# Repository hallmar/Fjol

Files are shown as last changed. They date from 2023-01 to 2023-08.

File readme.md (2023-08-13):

# Fjöl 4-Voice Midi synth
# FIRMWARE AND HARDWARE STILL A WORK IN PROGRESS

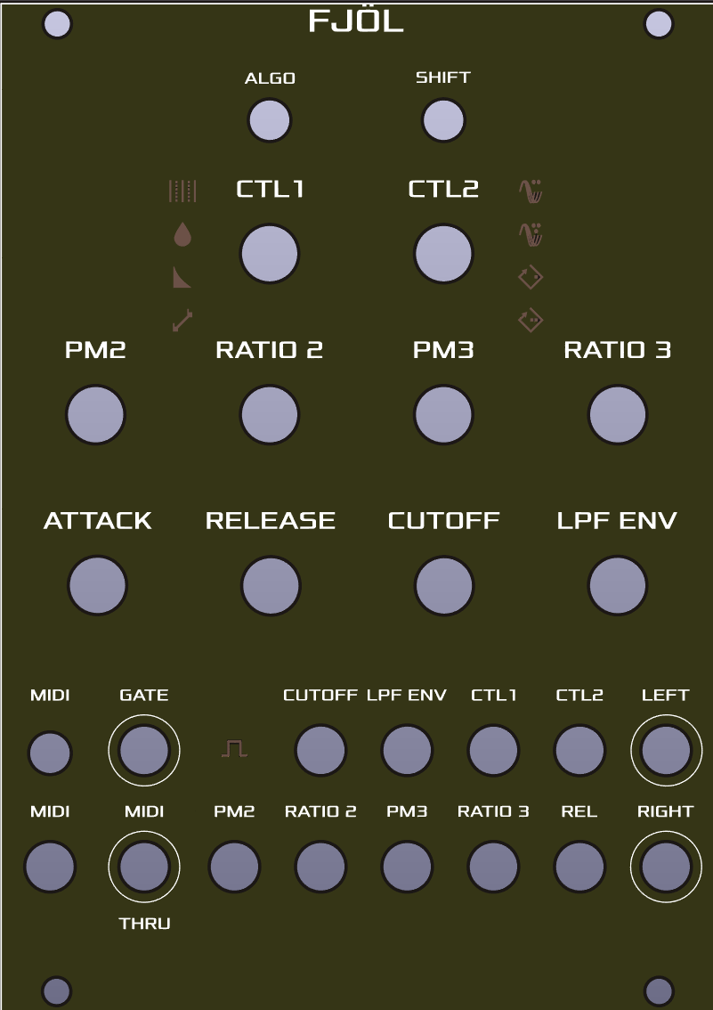
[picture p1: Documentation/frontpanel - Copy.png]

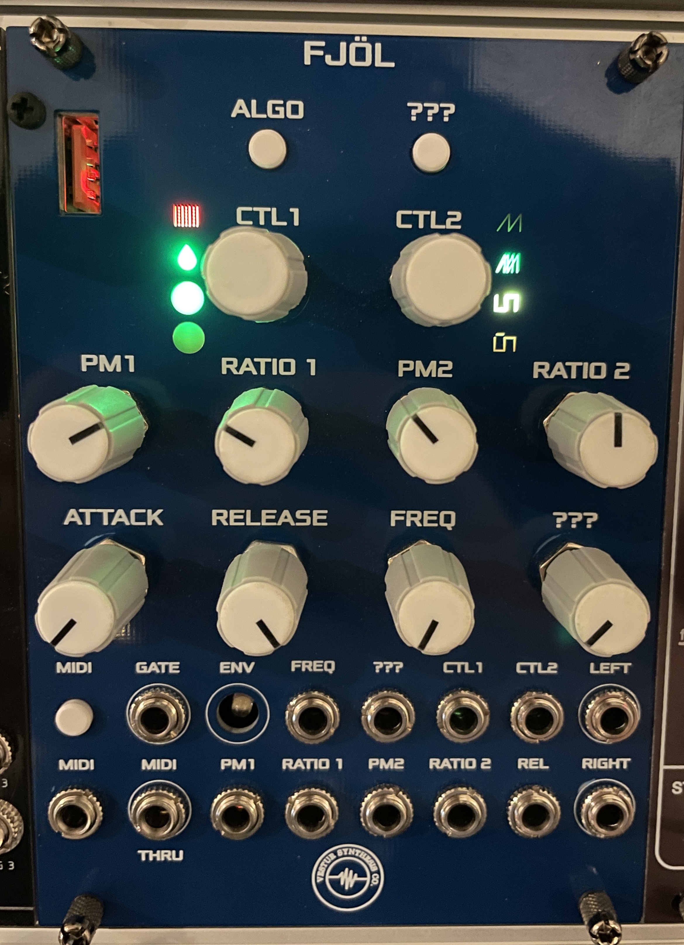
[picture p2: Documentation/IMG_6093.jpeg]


Small demo video with non working LED's: https://www.youtube.com/watch?v=nTqA_WNiwQo

Current hardware uses the [Daisy Seed](https://www.electro-smith.com/daisy) platform from Electrosmith, which has 96kHz/24Bit stereo audio.

Fjöl is a 
4 voice polyphonic Phase modulation synthesizer. Using only sine waves you can get the same sounds as an FM synthesizer.

* digital ladder LPF with resonance
* usb A on the back to update firmware
* 3 operator Phase modulation with 3 algorithms(so far)
* two endless encoders with CV input for adjusting 8 different parameters 
* MIDI IN and MIDI THRU with type A midi minijacks as per MIDI standard.
* optional V/OCT and gate per voice expander also in the works

Encoder parameters are:

* stereo spread of voices(constant power)
* filter resonance
* filter envelope decay
* glide/portamento
* Operator 2 detune
* Operator 3 detune
* Operator 1 feedback (creates saw like wave)
* Operator 2 feedback

Potentiometers are:

* Operator 2 amplitude
* Operator 2 ratio
* Operator 3 amplitude
* Operator 3 ratio
* VCA Attack 
* VCA Release
* LPF frequency
* Filter envelope amplitude

Algorithms so far:

### Algo 1: 

OP2 -> OP1

OP3 -> OP1

### Algo 2:

OP3 -> OP2 -> OP1

### Algo 3:

OP3 -> OP1

OP2 -> OUT

## Where/how to order
It's all a work in progress.

~~Hopefully I'll have some beta testing units ready before summer 2023 :)~~

WELL that didn't work out. Putting this one on hiatus until I finalize the desktop version.
It's a struggle to work a full time job and try and work on this regularily.

## Designed With

* KiCAD
* Visual Studio Code(C++)
* Inkscape

## Versioning
* 1.0 - [Hardware] Original PCB
* 1.0 - [Software] Original software 
## Authors

* **Hallmar Gauti Halldórsson** - Fjöl Hardware and Firmware
* **Electrosmith** - libDaisy and DaisySP libraries

## License
Hardware: CC BY-SA 4.0

Software: CC BY-SA 4.0

But if you want to sell or do something with the software or hardware then it'd be nice to include my name and link to my Github somewhere :)

## Acknowledgments

* All of Mutable Instruments designs have been an insparation and a solid reference for both analog and digital circuits.
https://github.com/pichenettes/eurorack

* The whole idea of a 4 voice poly synth was planted in my head after trying MakeSynthsNotWar's String Theory module.
https://makesynthsnotwar.com/modules/stringtheory/

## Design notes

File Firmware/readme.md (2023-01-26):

# File Structure:
* **Fjol.cpp** is the main file that sets up all the hardware, reads ADC values and ect.
* **led-enc.cpp** this contains the functions to map values for the LED's and a function to return velocity sensitive values from encoders
* **midi.cpp** this contains all the midi functions that handle midi messages
* **variables.cpp** and **variables.h** contain all of the globally declared variables.
* **settings.h** contains all function declerations
* **calibrate.cpp** contains the function for calibrating CV and potentiometer values
* **makefile** contains the build info for this project

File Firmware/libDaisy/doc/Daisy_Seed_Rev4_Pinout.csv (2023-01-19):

 | SCH name | Pin name | ADC | Arduino D# | Arduino A# | I2C | UART | SPI
1 | USB_HS_ID | PB12 | x | D0 |  |  | UART5_RX | SPI2_NSS/I2S2_WS | TIM1_BKIN |  |  | DFSDM1_DATIN1 | USART3_CK | FDCAN2_RX | OTG_HS_ULPI_D5 | ETH_MII_TXD0/ETH_RMII_TXD0 | OTG_HS_ID | TIM1_BKIN_COMP12 |  | EVENTOUT
2 | SDMMC1_D3 | PC11 | x | D1 |  |  | USART3_RX/UART4_RX | SPI3_MISO/ I2S3_SDI | HRTIM_FLT2 | DFSDM1_DATIN5 |  |  |  | QUADSPI_BK2_NCS | SDMMC1_D3 | DCMI_D4 | EVENTOUT
3 | SDMMC1_D2 | PC10 | x | D2 |  |  | USART3_TX/UART4_TX | SPI3_SCK/I2S3_CK | HRTIM_EEV1 | DFSDM1_CKIN5 |  |  |  | QUADSPI_BK1_IO1 | SDMMC1_D2 | DCMI_D8 | LCD_R2 | EVENTOUT
4 | SDMMC1_D1 | PC9 | x | D3 |  | I2C3_SDA |  |  | MCO2 | TIM3_CH4 | TIM8_CH4 |  | I2S_CKIN | UART5_CTS | QUADSPI_BK1_IO0 | LCD_G3 | SWPMI_SUSPEND | SDMMC1_D1 | DCMI_D3 | LCD_B2 | EVENTOUT
5 | SDMMC1_D0 | PC8 | x | D4 |  |  |  |  | TRACED1 | HRTIM_CHB1 | TIM3_CH3 | TIM8_CH3 | USART6_CK | UART5_RTS/UART5_DE | FMC_NE2/FMC_NCE | SWPMI_RX | SDMMC1_D0 | DCMI_D2 | EVENTOUT
6 | SDMMC1_CMD | PD2 | x | D5 |  |  | UART5_RX |  | TRACED2 | TIM3_ETR |  | SDMMC1_CMD | DCMI_D11 | EVENTOUT
7 | SDMMC1_CK | PC12 | x | D6 |  |  | UART5_TX | SPI3_MOSI/I2S3_SDO | TRACED3 | HRTIM_EEV2 |  |  |  | SDMMC1_CK | DCMI_D9 | EVENTOUT
8 | SPI1_NSS | PG10 | x | D7 |  |  |  | SPI1_NSS/I2S1_WS | HRTIM_FLT5 |  | LCD_G3 |  | FMC_NE3 | DCMI_D2 | LCD_B2 | EVENTOUT
9 | SPI1_SCK | PG11 | x | D8 |  |  |  | SPI1_SCK/I2S1_CK | LPTIM1_IN2 | HRTIM_EEV4 |  | SPDIFRX1_IN1 | SDMMC2_D2 | ETH_MII_TX_EN/ETH_RMII_TX_ EN | DCMI_D3 | LCD_B3 | EVENTOUT
10 | SPI1_MISO | PB4 | x | D9 |  |  | UART7_TX | SPI1_MISO/I2S1_SDI/SPI3_MISO/I2S3_SDI/SPI2_NSS/I2S2_WS/SPI6_MISO | NJTRST | TIM16_BKIN | TIM3_CH1 | HRTIM_EEV6 |  |  |  |  | SDMMC2_D3 |  | EVENTOUT
11 | SPI1_MOSI | PB5 | x | D10 |  |  | UART5_RX | SPI1_MOSI/I2S1_SDO/SPI3_MOSI/I2S3_SDO/SPI6_MOSI | TIM17_BKIN | TIM3_CH2 | HRTIM_EEV7 |  |  |  |  |  | FDCAN2_RX | OTG_HS_ULPI_D7 | ETH_PPS_OUT | FMC_SDCKE1 | DCMI_D10 |  | EVENTOUT
12 | I2C1_SCL | PB8 | x | D11 |  | I2C1_SCL/I2C4_SCL | UART4_RX |  | TIM16_CH1 | TIM4_CH3 | DFSDM1_CKIN7 |  |  | SDMMC1_CKIN |  | FDCAN1_RX | SDMMC2_D4 | ETH_MII_TXD3 | SDMMC1_D4 | DCMI_D6 | LCD_B6 | EVENTOUT
13 | I2C1_SDA | PB9 | x | D12 |  | I2C1_SDA/I2C4_SDA | UART4_TX | SPI2_NSS/I2S2_WS | TIM17_CH1 | TIM4_CH4 | DFSDM1_DATIN7 |  |  |  | SDMMC1_CDIR |  | FDCAN1_TX | SDMMC2_D5 |  | SDMMC1_D5 | DCMI_D7 | LCD_B7 | EVENTOUT
14 | USART1_TX | PB6 | x | D13 |  | I2C1_SCL/I2C4_SCL | USART1_TX/LPUART1_TX/UART5_TX |  | TIM16_CH1N | TIM4_CH1 | HRTIM_EEV8 |  | CEC |  |  |  | FDCAN2_TX | QUADSPI_BK1_NCS | DFSDM1_DATIN5 | FMC_SDNE1 | DCMI_D5 |  | EVENTOUT
15 | USART1_RX | PB7 | x | D14 |  | I2C1_SDA/I2C4_SDA | USART1_RX/LPUART1_RX |  | TIM17_CH1N | TIM4_CH2 | HRTIM_EEV9 |  |  |  |  | FDCAN2_TXFD_MODE | DFSDM1_CKIN5 | FMC_NL | DCMI_VSYNC | EVENTOUT
16 | AUDIO IN L | x | x | NC |  |  |  |  | x
17 | AUDIO INR | x | x | NC |  |  |  |  | x
18 | AUDIO OUT L | x | x | NC |  |  |  |  | x
19 | AUDIO OUT R | x | x | NC |  |  |  |  | x
20 | AGND | x | x | NC
21 | 3v3A | x | x | NC |  |  |  |  | x
22 | ADC_INP10 | PC0 | ADC12_INP10 | D15 | A0 |  |  |  | DFSDM1_CKIN0 | DFSDM1_DATIN4 |  | OTG_HS_ULPI_STP | FMC_SDNWE | LCD_R5 | EVENTOUT
23 | ADC_INP15 | PA3 | ADC12_INP15 | D16 | A1 |  | USART2_RX |  | TIM2_CH4 | TIM5_CH4 | LPTIM5_OUT | TIM15_CH2 |  | LCD_B2 | OTG_HS_ULPI_D0 | ETH_MII_COL | LCD_B5 | EVENTOUT
24 | ADC_INP5 | PB1 | ADC12_INP5 | D17 | A2 |  |  |  | TIM1_CH3N | TIM3_CH4 | TIM8_CH3N | DFSDM1_DATIN1 | LCD_R6 | OTG_HS_ULPI_D2 | ETH_MII_RXD3 | LCD_G0 | EVENTOUT
25 | ADC_INP7 | PA7 | ADC12_INP7 | D18 | A3 |  |  | SPI1_MOSI/I2S1_SDO/SPI6_MOSI | TIM1_CH1N | TIM3_CH2 | TIM8_CH1N |  |  | TIM14_CH1 | ETH_MII_RX_DV/ETH_RMII_CRS _DV | FMC_SDNWE | EVENTOUT
26 | ADC_INP3 | PA6 | ADC12_INP3 | D19 | A4 |  |  | SPI1_MISO/I2S1_SDI/SPI6_MISO | TIM1_BKIN | TIM3_CH1 | TIM8_BKIN |  |  | TIM13_CH1 | TIM8_BKIN_COMP12 | MDIOS_MDC | TIM1_BKIN_COMP12 | DCMI_PIXCLK | LCD_G2 | EVENTOUT
27 | ADC_INP11 | PC1 | ADC123_INP11 | D20 | A5 |  |  | SPI2_MOSI/I2S2_SDO | TRACED0 | SAI1_D1 | DFSDM1_DATIN0 | DFSDM1_CKIN4 |  | SAI1_SD_A | SAI4_SD_A | SDMMC2_CK | SAI4_D1 | ETH_MDC | MDIOS_MDC | EVENTOUT
28 | ADC1_INP4 | PC4 | ADC12_INP4 | D21 | A6 |  |  |  | DFSDM1_CKIN2 | I2S1_MCK | SPDIFRX1_IN3 | ETH_MII_RXD0/ETH_RMII_RXD0 | FMC_SDNE0 | EVENTOUT
29 | DAC1_OUT2 | PA5 | ADC12_INP19 | D22 | A7 |  |  | SPI1_SCK/I2S1_CK/SPI6_SCK | D2PWREN | TIM2_CH1/TIM2_ETR | TIM8_CH1N |  |  | OTG_HS_ULPI_CK | LCD_R4 | EVENTOUT
30 | DAC1_OUT1 | PA4 | ADC12_INP18 | D23 | A8 |  |  | SPI1_NSS/I2S1_WS/SPI3_NSS/I2S3_WS/SPI6_NSS | D1PWREN | TIM5_ETR |  |  | USART2_CK |  | OTG_HS_SOF | DCMI_HSYNC | LCD_VSYNC | EVENTOUT
31 | SAI2_MCLK_B | PA1 | ADC1_INP17 | D24 | A9 |  | UART4_RX |  | TIM2_CH2 | TIM5_CH2 | LPTIM3_OUT | TIM15_CH1N | USART2_RTS/USART2_DE |  | QUADSPI_BK1_IO3 |  | ETH_MII_RX_CLK/ETH_RMII_RE F_CLK | LCD_R2 | EVENTOUT
32 | SAI2_SD_B | PA0 | ADC1_INP16 | D25 | A10 |  | UART4_TX |  | TIM2_CH1/TIM2_ETR | TIM5_CH1 | TIM8_ETR | TIM15_BKIN | USART2_CTS/USART2_NSS |  | SDMMC2_CMD |  | ETH_MII_CRS | EVENTOUT
33 | SAI2_SD_A | PD11 | x | D26 |  |  |  |  | LPTIM2_IN2 |  | USART3_CTS/USART3_NSS | QUADSPI_BK1_IO0 |  | FMC_A16 | EVENTOUT
34 | SAI2_FS_B | PG9 | x | D27 |  |  | USART6_RX | SPI1_MISO/I2S1_SDI |  |  | SPDIFRX1_IN4 | QUADSPI_BK2_IO2 |  | FMC_NE2/FMC_NCE | DCMI_VSYNC | EVENTOUT
35 | SAI2_SCK_B | PA2 | ADC12_INP14 | D28 | A11 |  | USART2_TX |  | TIM2_CH3 | TIM5_CH3 | LPTIM4_OUT | TIM15_CH1 |  |  | ETH_MDIO | MDIOS_MDIO | LCD_R1 | EVENTOUT
36 | USB_HS_D_- | PB14 | x | D29 |  |  | USART1_TX | SPI2_MISO/I2S2_SDI | TIM1_CH2N | TIM12_CH1 | TIM8_CH2N |  |  | DFSDM1_DATIN2 | USART3_RTS/USART3_DE | UART4_RTS/UART4_DE | SDMMC2_D0 | OTG_HS_DM | EVENTOUT
37 | USB_HS_D_+ | PB15 | x | D30 |  |  | USART1_RX | SPI2_MOSI/I2S2_SDO | RTC_REFIN | TIM1_CH3N | TIM12_CH2 | TIM8_CH3N |  |  | DFSDM1_CKIN2 | UART4_CTS | SDMMC2_D1 | OTG_HS_DP | EVENTOUT
38 | 3v3D | x | x |  |  |  |  |  | x
39 | VIN | x | x |  |  |  |  |  | x
40 | GND | x | x |  |  |  |  |  | x
INTERNAL
MEM1 | QSPI | QSPI FLASH 8MB
MEM2 | SDRAM | SDRAM 64MB
 | USB FS D+ | USB FS
 | USB FS D- | USB FS
 |  |  |  |  |  |  |  |  |  |  |  |  |  | LPUART1_TX
internal SAI | I2C2 |  |  |  |  |  |  |  |  |  |  |  |  | LPUART1_RX
 | SAI1_MCLK_A | PE2 |  |  |  |  |  |  |  |  |  |  |  | UART4_RX
 | SAI1_SD_B | PE3 |  |  |  |  |  |  |  |  |  |  |  | UART4_TX
 | SAI1_FS_A | PE4 |  |  |  |  |  |  |  |  |  |  |  | UART5_RX
 | SAI1_SCK_A | PE5 |  |  |  |  |  |  |  |  |  |  |  | UART5_TX
 | SAI1_SD_A | PE6 |  |  |  |  |  |  |  |  |  |  |  | UART7_RX
 |  |  |  |  |  |  |  |  |  |  |  |  |  | UART7_TX
 |  |  |  |  |  |  |  |  |  |  |  |  |  | USART1_RX
On Board User LED | PC7 |  |  | D31 |  |  |  |  |  |  |  |  |  | USART1_TX
On Board Test Point | PG14 |  |  |  |  |  |  |  |  |  |  |  |  | USART2_RX
 |  |  |  |  |  |  |  |  |  |  |  |  |  | USART2_TX
BOOT | PG3 |  |  |  |  |  |  |  |  |  |  |  |  | USART3_RX
QSPI GPIO |  |  |  |  |  |  |  |  |  |  |  |  |  | USART3_TX
IO0 | PF8 |  |  |  |  |  |  |  |  |  |  |  |  | USART6_RX
IO1 | PF9
IO2 | PF7
IO3 | PF6
CLK | PF10
NCS | PG6

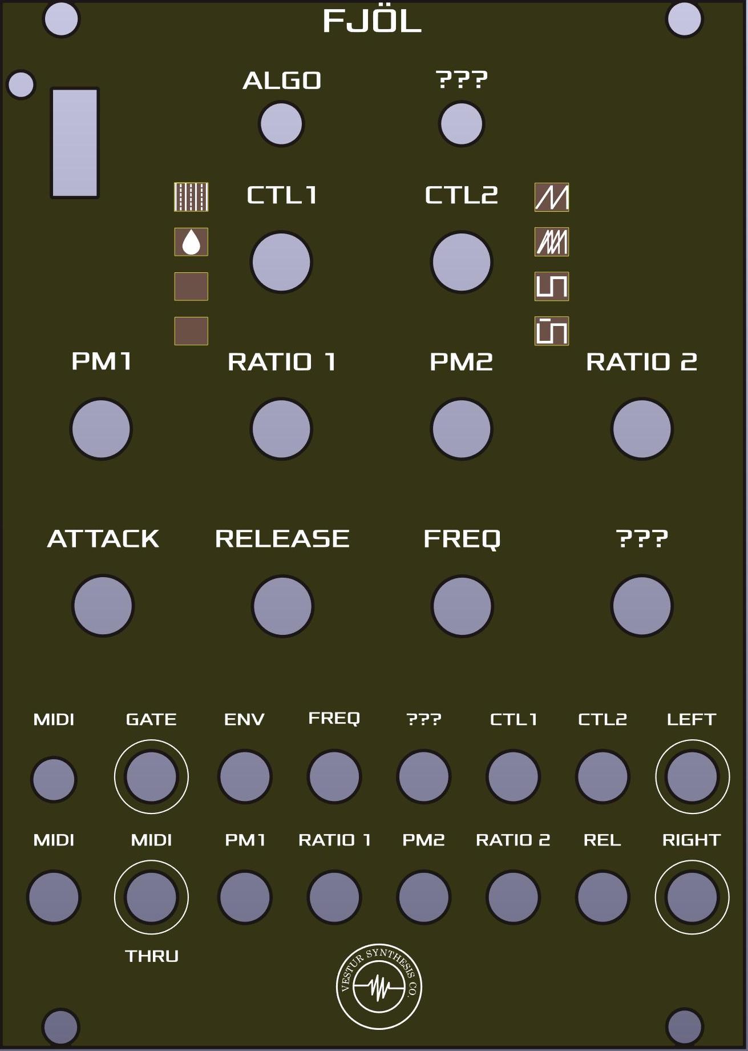
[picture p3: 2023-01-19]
Hardware/frontpanel/frontpanel(1).jpg

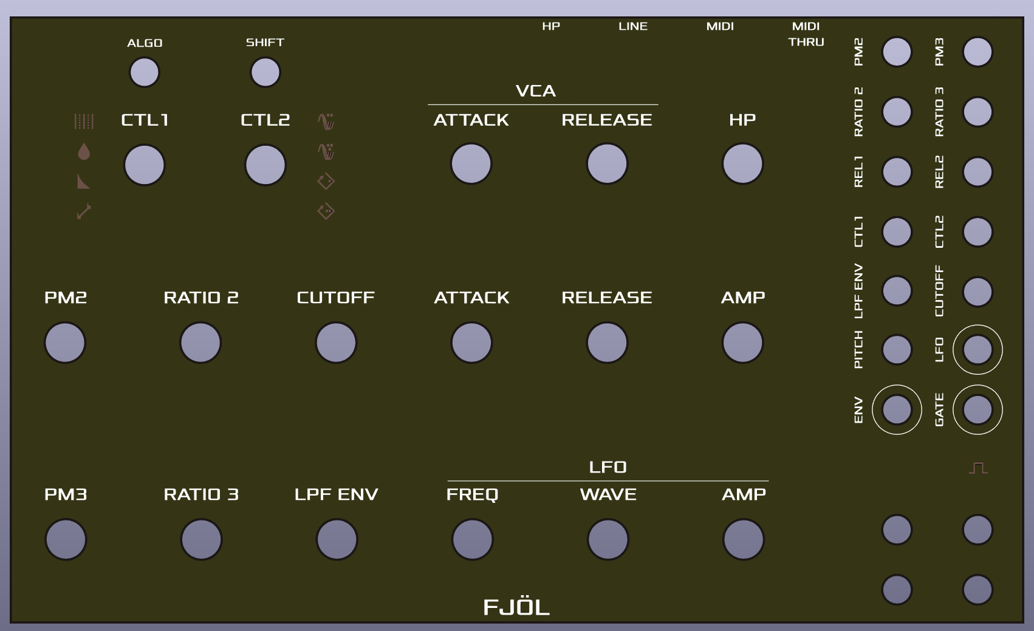
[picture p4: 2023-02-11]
Hardware/frontpanel/Screenshot 2023-02-08 221054.png

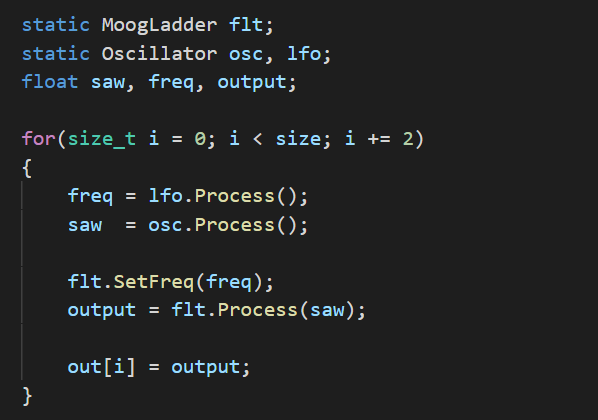
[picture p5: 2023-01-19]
Firmware/DaisySP/resources/assets/code_example.PNG

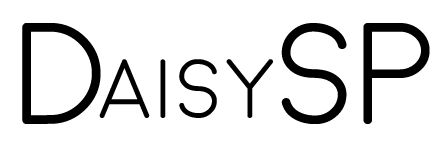
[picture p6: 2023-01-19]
Firmware/DaisySP/resources/assets/daisysp.png

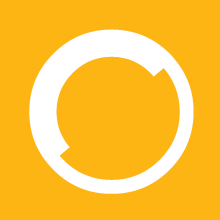
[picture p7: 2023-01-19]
Firmware/libDaisy/doc/images/ES_Circle_Orange.PNG

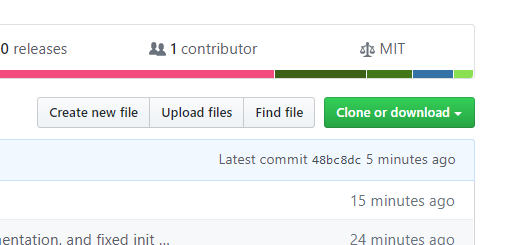
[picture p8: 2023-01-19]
Firmware/DaisySP/resources/download.PNG

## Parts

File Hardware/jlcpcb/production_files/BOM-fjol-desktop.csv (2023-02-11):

Comment | Designator | Footprint | LCSC
22u | C10,C2,C6,C7 | C_Elec_5x5.8 | C128468
LM4040DBZ-10 | U4 | SOT-23 | C129969
470n | C14,C18 | C_0805_2012Metric | C13967
100k | R10,R12,R14,R16,R18,R24,R27,R29,R45,R46,R56,R67,R69 | R_0805_2012Metric | C149504
741G17DBV | IC1 | SOT-23-5_HandSoldering | C151394
100 | R30,R35,R36,R37,R47,R48,R52,R53,R64,R65,R72,R73,R74,R75,R76,R77,R78,R79 | R_0805_2012Metric | C17408
10k | R40,R42,R43,R82,R83,R84,R85,R86,R87,R88,R89 | R_0805_2012Metric | C17414
10 | R51 | R_0805_2012Metric | C17415
140k 1% | R55 | R_0805_2012Metric | C17460
1k | R2,R3,R38,R41,R5,R6,R7 | R_0805_2012Metric | C17513
200k | R11,R13,R15,R17,R23,R25,R26,R28,R39,R44,R66,R68 | R_0805_2012Metric | C17539
220 | R1 | R_0805_2012Metric | C17557
22k | R8,R9 | R_0805_2012Metric | C17560
33k | R49,R54,R57 | R_0805_2012Metric | C17633
33 | R50 | R_0805_2012Metric | C17634
470 | R4 | R_0805_2012Metric | C17710
66.5k | R19,R20,R21,R22,R31,R32,R33,R34,R70,R71 | R_0805_2012Metric | C17791
100p | C30,C31 | C_0805_2012Metric | C1790
2.2u | L12,L2,L3 | L_0805_2012Metric | C193676
1N4148 | D3 | D_SOD-323 | C2128
BC847 | Q1 | SOT-23 | C2138
6N138 | U3 | DIL8-SMD | C255744
NCP1117-3.3_SOT223 | U11 | SOT-223-3_TabPin2 | C26537
LM4810 | U5 | TSSOP-8_3x3mm_P0.65mm | C2871753
AudioJack3 | headphone1,line1 | Jack_3.5mm_CUI_SJ-3523-SMT_Horizontal | C2910522
220u | C21,C22 | CP_Elec_5x5.8 | C2977551
100u | C44,C5 | C_Elec_5x5.8 | C336761
USB_B | J1 | USB_Micro-B_GCT_USB3076-30-A | C393940
33u | L6 | L_0805_2012Metric | C404761
MCP6001-OT | U13 | SOT-23-5 | C412821
1n | C23,C32,C33,C34,C35,C38,C40,C41,C42,C8,C9 | C_0805_2012Metric | C46653
100n | C1,C11,C12,C13,C15,C16,C17,C19,C20,C24,C3,C37,C39,C4,C43,C45,C46,C51,C52 | C_0805_2012Metric | C49678
TL072 | U6 | SO-8_3.9x4.9mm_P1.27mm | C6961
MCP6004 | U10,U7,U9 | SOIC-14_3.9x8.7mm_P1.27mm | C7378
BLM21AG102SN1D | L10,L11,L8,L9 | L_0805_2012Metric | C85835
74HC4051D | U8 | SOIC-16_4.55x10.3mm_P1.27mm | C9386
PESE1-S5-D12-M-TR | U2 | PESE1
PCA9622 | U12 | TSSOP-32_6.1x11mm_P0.65mm
SW_SPST | SW1 | SW_E-Switch_EG1224_SPDT_Angled

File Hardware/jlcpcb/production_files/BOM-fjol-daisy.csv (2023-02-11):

Comment | Designator | Footprint | LCSC
22u | C10,C6,C7 | C_Elec_5x5.8 | C128468
LM4040DBZ-10 | U4 | SOT-23 | C129969
100k 1% | R10,R12,R14,R16,R18,R24,R27,R29,R44,R45,R46,R61,R63,R67,R69 | R_0805_2012Metric | C149504
Conn_02x05_Odd_Even | J2 | PinHeader_2x05_P1.27mm_Vertical_SMD | C150517
741G17DBV | IC1 | SOT-23-5_HandSoldering | C151394
STPS1L30U | D1,D2 | D_SMB | C157388
100 | R30,R35,R36,R37,R52,R53,R64,R65,R72,R73,R74,R75,R76,R77,R78,R79 | R_0805_2012Metric | C17408
10k | R40,R42,R43,R48,R49,R58,R59,R82,R83,R84,R85,R86,R87,R88,R89 | R_0805_2012Metric | C17414
10 | R51 | R_0805_2012Metric | C17415
140k 1% | R47,R60,R62,R9 | R_0805_2012Metric | C17460
1k | R2,R3,R38,R41,R5,R54,R55 | R_0805_2012Metric | C17513
200k | R11,R13,R15,R17,R23,R25,R26,R28,R66,R68 | R_0805_2012Metric | C17539
220 | R1 | R_0805_2012Metric | C17557
33k 1% | R56,R57,R80,R81 | R_0805_2012Metric | C17633
33 | R50 | R_0805_2012Metric | C17634
470 | R4 | R_0805_2012Metric | C17710
47k | R7,R8 | R_0805_2012Metric | C17713
66.5k | R19,R20,R21,R22,R31,R32,R33,R34,R70,R71 | R_0805_2012Metric | C17791
100p | C30,C31 | C_0805_2012Metric | C1790
Conn_01x16_Male | J7 | PinHeader_2x08_P2.54mm_Vertical_SMD | C188235
BC847 | Q1,Q2,Q3,Q4,Q5 | SOT-23 | C2138
6N138 | U3 | DIL8-SMD | C255744
Conn_01x10_Female | J10,J6 | PinSocket_2x05_P2.54mm_Vertical_SMD | C261072
NCP1117-3.3_SOT223 | U11,U2 | SOT-223-3_TabPin2 | C26537
PCA9622 | U12 | TSSOP-32_6.1x11mm_P0.65mm | C2678561
100u | C2,C44,C5 | C_Elec_5x5.8 | C336761
Conn_01x16_Female | J8 | PinSocket_2x08_P2.54mm_Vertical_SMD | C3975153
33u | L12,L2,L6 | L_0805_2012Metric | C404761
1n | C20,C21,C22,C23,C32,C33,C34,C35,C38,C40,C41,C42,C8,C9 | C_0805_2012Metric | C46653
100n | C1,C11,C13,C15,C16,C17,C19,C24,C3,C36,C37,C39,C4,C43,C45,C46,C51,C52 | C_0805_2012Metric | C49678
TL072 | U6 | SO-8_3.9x4.9mm_P1.27mm | C6961
MCP6002 | U13 | SOIC-8-1EP_3.9x4.9mm_P1.27mm_EP2.514x3.2mm | C7377
MCP6004 | U10,U7,U9 | SOIC-14_3.9x8.7mm_P1.27mm | C7378
BLM21AG102SN1D | L10,L11,L4,L5,L7,L8,L9 | L_0805_2012Metric | C85835
Conn_01x18_Male | J5 | PinHeader_2x09_P2.54mm_Vertical_SMD | C88175
Conn_01x18_Female | J9 | PinSocket_2x09_P2.54mm_Vertical_SMD | C920936
74HC4051D | U8 | SOIC-16_4.55x10.3mm_P1.27mm | C9386
33u | L1 | L_1206_3216Metric
1N4148 | D3 | D_0805_2012Metric
PESE1 | U1 | PESE1
50k-lin | ATTACK1 | 9MM_SNAP-IN_POT
50k-lin | cutoff1 | 9MM_SNAP-IN_POT
50k-lin | RELEASE1 | 9MM_SNAP-IN_POT
50k-lin | CTL2 | 9MM_SNAP-IN_POT
Conn_02x08_Odd_Even | J1 | con-3m-PAK100_2500-16
ctl1 | SW3 | RotaryEncoder_Alps_EC11E-Switch_Vertical_H20mm
ctl2 | SW4 | RotaryEncoder_Alps_EC11E-Switch_Vertical_H20mm
LED_Dual_KAK | D5 | LED_D3.0mm-3
LED_Dual_KAK | D6 | LED_D3.0mm-3
LED_Dual_KAK | D7 | LED_D3.0mm-3
LED_Dual_KAK | D8 | LED_D3.0mm-3
LED_Dual_KAK | D9 | LED_D3.0mm-3
LED_Dual_KAK | D10 | LED_D3.0mm-3
LED_Dual_KAK | D11 | LED_D3.0mm-3
LED_Dual_KAK | D12 | LED_D3.0mm-3
50k-lin | PM2 | 9MM_SNAP-IN_POT
50k-lin | RATIO1 | 9MM_SNAP-IN_POT
50k-lin | RATIO2 | 9MM_SNAP-IN_POT
50k-lin | PM1 | 9MM_SNAP-IN_POT
Device_Audio_Electrosmith_Daisy_Seed_Rev4 | A1 | Device_Audio_Electrosmith_Daisy_Seed
KUSBVX | X1 | USB_A_Molex_67643_Horizontal
LED | D4 | LED_D3.0mm

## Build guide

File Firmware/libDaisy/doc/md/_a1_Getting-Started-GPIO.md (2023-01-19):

# Getting Started - GPIO

GPIO stands for General Purpose Input/Output. These are common to microcontrollers of all sizes, and are one of the many ways to work with external components.

GPIO are used as the basis for several interface components including switches, LEDs, encoders, etc.

The Daisy exposes several GPIO on its pinout. Most of these pins can do much more than just be a digital input or output, but we'll keep it simple for now.

Below, we'll discuss the code, hardware, and provide a few examples of how to use the GPIO within the Daisy ecosystem.

## The CPP Objects Used

We'll be using the `DaisySeed`, `Pin`, and `GPIO` objects in the following sections.

If you're using a different Daisy SOM (i.e. DaisyPatchSM, etc.) this still applies, but some of the pin names will be different.

The `DaisySeed` object is a class that manages all of the hardware on the Seed board. All we need to do with it for now is initialize it.

The `Pin` class is used to describe a specific physical pin on the hardware. These objects are used to initialize GPIO, but are also used in the configuration of more complex peripherals and devices (i.e. ADCs, Shift Registers, etc.).

The `GPIO` class is used for the basic reading/writing of a digital signal.

When we talk about "digital" signals, we mean a signal that has only two states, HIGH and LOW.

## The Hardware Connections

For the examples below we'll be using a few components. These can be replaced with a number of similar alternatives.

* [Mini Pushbutton](https://www.electro-smith.com/parts/pushbuttons)
* [3mm LED](https://www.electro-smith.com/parts/3mm-leds)
* Resistor(s) any low value (1-10K should work okay in the examples discussed below)

## GPIO Input

One of the simplest uses of a GPIO is to read the state of a button.

For this example we'll use a simple [mini pushbutton](https://www.electro-smith.com/parts/pushbuttons) to read the state of a button.

The easiest way to wire up a switch like this is to connect one set of legs (pins 1 and 2) to the GPIO input, and connect the other two legs (pins 3 and 4) to GND.

A very short example of a program to do this looks like:

```cpp
#include "daisy_seed.h"

using namespace daisy;
using namespace daisy::seed;

DaisySeed hw;

int main(void) {
  // Initialize the Daisy Seed
  hw.Init();

  // Create a GPIO object
  GPIO my_button;

  // Initialize the GPIO object
  my_button.Init(D0, GPIO::Mode::INPUT, GPIO::Pull::PULLUP);

  while(1) {
    // And let's store the state of the button in a variable called "button_state"
    bool button_state = my_button.Read();
  }
}
```

If you haven't followed the guides on [setting up your development enviornment](https://github.com/electro-smith/DaisyWiki/wiki/1.-Setting-Up-Your-Development-Environment) and [creating a new project](https://github.com/electro-smith/DaisyWiki/wiki/How-To:-Create-a-New-Project) now would be a perfect time to catch up, and create a new project to work with the GPIO.

Compiling this example, you might get a warning, for an "unused variable button_state", but we'll get to using that shortly!

## Breaking Down the Init function

Let's look at that GPIO init function in a bit more detail, shall we? First, we'll breakdown the full Initialization definition:

```cpp
void Init(Pin p, Mode m=Mode::INPUT, Pull pu=Pull::NOPULL, Speed sp=Speed::LOW);
```

The first thing you may be wondering, if you're not used to C++ is the `::` characters all over the place. These are used for the configuration settings so that the compiler will only allow you to use the correct inputs instead of being able to pass the wrong thing to the input, or even just mis-order the arguments, and end up scratching your head for hours wondering what's not working.

These `::` are also used for namespaces, which we handle in the above example with the `using namespace` lines. Without that we'd have to use `daisy::GPIO` instead of `GPIO`, `daisy::seed::D0` instead of `D0`, etc.

### Pin Argument

So, the first argument: `Pin p` describes the daisy pin to assign to our GPIO, this ties our new GPIO object to some of the actual hardware on the Daisy Seed. By using `D0` (or more explicitly, `daisy::seed::D0`), we're saying we want to use that pin for our GPIO.

### Mode Argument

The second argument: `Mode m` can be any of the following:

* `Mode::INPUT` - configures the pin as an input
* `Mode::OUTPUT` - configures the pin as an output (in push pull configuration)
* `Mode::OUTPUT_OD` - also an output, but the transistor connection to pull the signal to GND is not connected, this is less commonly used.
* `Mode::ANALOG` - configures the GPIO for connection to the ADC or DAC peripherals within the micro controller.

If you only supply the `Pin` argument, the GPIO will default to `Mode::INPUT` configuration.

### Pull Argument

The third argument: `Pull pu` is used to select whether the GPIO will use an internal (around 30-50k) resistor as a pull up or pull down resistor.

A pull up resistor will keep the GPIO idling at 3V3 unless something pulls it down, while a pull down resistor will keep a GPIO idling at 0V unless something pulls it up.

The options for this argument are:

* `Pull::NOPULL` - no pull up or pull down resistor is connected.
* `Pull::PULLUP` - pull up resistor is connected to the GPIO line.
* `Pull::PULLDOWN` - pull down resistor is connected to the GPIO line.

This argument will default to `Pull::NOPULL` if you only supply a `Pin` and a `Mode`

So when, and why do we need pull up or pull down resistors anyway?

Well, if we connect a wire to one of Daisy's GPIO pins, and there are no internal or external resistors attached, there's no definite way to know what voltage the wire is sitting at.

Now, if we connect the wire to a button, as we did in the above example, and connect the other side of the button to 3V3 then we _do_ know the voltage at the pin when the button pressed.
However, when the button is not pressed, we still have an "undefined" state, as we can't guarantee that the pin will be at 0V when the button isn't pressed.

To solve this unknown state issue, we can add a resistor to the pin that "pulls" the signal to GND when the button isn't actively pulling the voltage up to 3V3 (while pressed).

Instead of adding an external resistor to do this, we can use the built-in pull-down feature to accomplish the same thing.

In the example above, we did the same thing except we used the pull up resistor, and wired the button to GND. This usually just requires less wires, but the function is the same.

### Speed Argument

The final argument, `Speed sp` is a special configuration for Output modes that control the slew rate, or the speed at which it can switch from 0V to 3V. We won't go super in depth on that in this, but you'll always want it to be the lowest speed possible for a given application to reduce the amount of electrical noise emitted.

## GPIO Output

So you've got your button reading code, your board wired up, and you're probably thinking, "Great! So how can I tell if I've done this correctly!?".

Well, let's set up a second pin as an output to light up an LED when we push our button. That way we can tell everything we've done so far is working.

Setting up the GPIO output isn't much more work.

On your hardware, you'll want to take the second pin (right above the square D0 pin), and connect a resistor, and an LED in series. You'll want the **cathode** of the LED connected to GND, with the **anode** connected to the resistor, [as described here](https://makecode.adafruit.com/learnsystem/pins-tutorial/devices/led-connections).

Once you've got that set up we can add a few lines to our example.

In the Initialization section:

```cpp
GPIO my_led;

my_led.Init(D1, GPIO::Mode::OUTPUT);
```

And then we can use the `button_state` variable we were reading from the button earlier to control the state of the LED:

```cpp
while(1)
{
  // And let's store the state of the button in a variable called "button_state"
  bool button_state = my_button.Read();
  my_led.Write(button_state);
}
```

And that's it! Easy, right?

So you get that all set up, and you might be thinking, "Well, this is great, but the LED turns off when I push the button instead of turning it on, what the heck?"

That's because of the way we set up the button in the first step. Because we used the internal pull up resistor, to avoid adding extra parts to our board, the GPIO is returning true while the button is not pressed instead of what we might expect. Well, C++ has a very easy way of flipping that over.

```cpp
bool button_state = my_button.Read(); // state is false while button is pressed
bool button_pressed = !button_state; // "!" is a "not" operator, which will flip a bool var.
```

So all together, our short little light switch program will look something like:

```cpp
#include "daisy_seed.h"

using namespace daisy;
using namespace daisy::seed;

DaisySeed hw;

int main(void) {
  // Initialize the Daisy Seed
  hw.Init();

  // Create our GPIO object
  GPIO my_button;
  GPIO my_led;

  // Initialize the GPIO object for our button */
  my_button.Init(D0, GPIO::Mode::INPUT, GPIO::Pull::PULLUP);

  // Initialize the GPIO object for our LED
  my_led.Init(D1, GPIO::Mode::OUTPUT);

  while(1) {
    // And let's store the state of the button in a variable called "button_state"
    bool button_state = my_button.Read();

    // And we want to light up the LED while we're pressing the button 
    // so let's use the "!" to flip over the button_state
    my_led.Write(!button_state);
  }
}
```

## Further Reading

Topics coming soon:

* Working with ADCs
* Serial Printing over USB
* Using the Switch and LED classes instead of GPIO, and Why?

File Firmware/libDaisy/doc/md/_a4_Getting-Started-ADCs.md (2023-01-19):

# Getting Started - ADCs

ADC stands for Analog to Digital Converter. These are used to read in a variable signal. These variable signals can be anything from a potentiometer, photoresistor, external control voltage, etc.

On the Daisy, the ADC inputs expect a signal in the range of 0V to 3.3V, unless otherwise stated (e.g. The CV inputs on the Daisy Patch SM are set up to expect -5V to 5V, a common range for Modular Synthesizers).

In this tutorial we'll be using the Daisy Seed hardware, and we will go through the process of connecting a few inputs to one of the many available ADC pins.

## The CPP Objects Used

We'll be using the `DaisySeed`, it's internal `AdcHandle`, `Pin`, and `AdcChannelConfig` objects in the following sections.

If you're using a different Daisy SOM (i.e. DaisyPatchSM, etc.) this is handled within the board support files for all available inputs.

The `DaisySeed` object is a class that manages all of the hardware on the Seed board. All we need to do with it for now is initialize it.

The `AdcHandle` is a handler for the microcontroller's embedded Analog to Digital Converter. It is up to 16-bits, and can handle multiplexing several inputs.

The `Pin` class is used to describe a specific physical pin on the hardware. These objects are used to initialize GPIO, but are also used in the configuration of more complex peripherals and devices (i.e. ADCs, Shift Registers, etc.).

The `AdcChannelConfig` object is used to define each of the connections to the ADC, and the order in which the inputs will be read.

## The Hardware Connections

For this tutorial all we'll need is:

* a few potentiometers like these [9mm Plastic Shaft Pot with Pointers](https://www.electro-smith.com/parts/trimmer), but any potentiometer should do the trick.

To wire up the pot we'll want to connect pin 1 of the pot to GND, and pin 3 of the pot to 3v3_A, and the middle leg (pin 2) will now output a variable voltage from 0V to 3.3V; perfect for our expected input range.

When working with the Daisy and external hardware, **always connect the DGND and AGND pins outside of the Daisy**

## ADC Channel Config

libDaisy uses the STM32 ADC1 peripheral, which is a single ADC with several multiplexed inputs.

This makes setting it up a little different than something like a GPIO, because the ADC will scan through all of the configured inputs in the background without taking up CPU time.

To define what connections are made we will use the `AdcChannelConfig` class.

The AdcChannelConfig has two possible initialization functions:

* `InitSingle` - For configuring a single input to a single pin on the Daisy
* `InitMux` - For configuring several inputs from an external multiplexer (like CD4051) to a single pin on the Daisy

Below we'll only be using the `InitSingle` function, but stay tuned for a guide for connecting a ton of controls using external multiplexer in the future.

The `InitSingle` function takes an old version of the Daisy's `Pin` object, but it is compatible with the new pins. So anywhere you see, `dsy_gpio_pin` you can use the `Pin` object instead.

This structure, and the number of channels can then be passed to the `AdcHandle` to set everything up.

## A Single Input

Alright, enough talk. Let's plug some stuff in, and write some code!

We can take a look at all of the available ADC pins by looking at the [Pinout Diagram](https://github.com/electro-smith/DaisyWiki/wiki/2.-Daisy-Seed-Pinout). The ADC Pins are all labeled and colored in yellow.

Let's get started with pin `A0` (also known as `D15`), and wire up our potentiometer.

See the wiring mentioned above in the [Hardware Connections](#The-Hardware-Connections) for how to connect all of the legs of the pot, and take the wiper (middle leg), and connect that to the `A0` pin on the Daisy.

And here's a short program that will setup, and read from an ADC:

```cpp
#include "daisy_seed.h"

using namespace daisy;
using namespace daisy::seed;

// Create out Daisy Seed Hardware object
DaisySeed hw;

int main(void) {
  // Initialize the Daisy Seed hardware
  hw.Init();

  // Start logging for printing over serial
  hw.StartLog();

  // Create an ADC Channel Config object
  AdcChannelConfig adc_config;

  // Set up the ADC config with a connection to pin A0
  adc_config.InitSingle(A0);

  // Initialize the ADC peripheral with that configuration
  hw.adc.Init(&adc_config, 1);

  // Start the ADC
  hw.adc.Start();

  while(1) {
    // Read the first ADC that's configured. In our case, this is the only input.
    int value = hw.adc.Get(0);

    // In order to know that everything's working let's print that to a serial console:
    hw.PrintLine("ADC Value: %d", value);

    // Wait half a second (500 milliseconds)
    System::Delay(500);
  }
}
```

To find out more about the serial printing, and what software to use, see our [tutorial on working with Serial Printing](_a2_Getting-Started-Serial-Printing.md).

With the above program, you should see a number printing that moves from 0 to 65536 as you rotate the pot. Now, pots, and electronics aren't perfect.
So there's a chance that this may not reach those extremes, or it might reach them slightly before the edges of the potentiometer's range.
This will largely depend on the potentiometer you're using.

Now that's great and all, but it would be nicer to work with a number that is scaled between 0 and 1 instead (since that's more useful for doing other things).

We can actually get the value in that range instead by changing the line where we were doing:

```cpp
int value = hw.adc.Get(0); // value will be 0-65536
```

to this Instead:

```cpp
float value = hw.adc.GetFloat(0); // value will be 0.0 to 1.0
```

floating point numbers have a few peculiarities because of the hardware and memory requirements of an embedded project, but you can keep the serial printing by adding the following to the project Makefile:

```make
LDFLAGS += -u _printf_float
```

This isn't included by default because it increases the flash size by several kilobytes, and there are other ways to print floating point numbers (more info on this in the [serial printing tutorial](tutorial)).

## Multiple Inputs

Most things get better when you add more of whatever it is. The same goes for controls!

Now we've set up a single pot. So let's look at what it would look like to hook up two (or more).

Nearly everything will stay the same except instead of using a single `AdcChannelConfig`, we'll want to create one for each control we want to use. C and C++ have a mechanism for dealing with this known as an array. If you're not familiar, it is basically just an ordered list.

So for setting up two pots we'll change the initialization code to look a little more like:

```cpp
// Create an array of two AdcChannelConfig objects
const int num_adc_channels = 2;
AdcChannelConfig my_adc_config[num_adc_channels];
// Initialize the first one connected to A0
my_adc_config[0].InitSingle(A0);
// Initialize the second one connected to A4
my_adc_config[1].InitSingle(A4);
```

And finally when we go to initialize the ADC itself, we can now omit the `&` that we had to use before because it's an array of objects, and we want to make sure to update the total count that we passed in before:

```cpp
hw.adc.Init(my_adc_config, num_adc_channels);
```

Now you can read from either input. If you want to read the pot connected to A0 you would use `hw.adc.Get(0)`, or `hw.adc.GetFloat(0)`, and if you want to read from the pot connected to A4, you would use `hw.adc.Get(1)`, or `hw.adc.GetFloat(1)`.

You'll notice that you access them by the order in which you initialized them, not by the number associated with the Pin.

## Order To Chaos - Naming ADC Channels

Once you have a lot of ADC channels, it can be difficult to remember which channel corresponds to which control. To solve this, you can use `enum`s to assign names to channels like this:

```cpp
enum AdcChannel {
   pitchKnob = 0,
   pitchCv,
   gainKnob,
   gainCv,
   NUM_ADC_CHANNELS
}
```

Here, the first value is assigned to `0`and the others increment automatically. Interestingly, this logic can be used to automatically get the total number of channels you use, by adding one last value `NUM_ADC_CHANNELS`. Of course you could also specify the individual values by hand, just add `myKnob = 3,`.

Now you can make your code much easier to read - and maintain, should you decide to change the hardware connections later:

```cpp
AdcChannelConfig my_adc_config[NUM_ADC_CHANNELS];
// ...
my_adc_config[pitchCv].InitSingle(A0);
// ...
hw.adc.Init(my_adc_config, NUM_ADC_CHANNELS);
// ...
const float pitchCvValue = hw.adc.GetFloat(pitchCv);
```

## Using Different Kinds of Inputs

OK. So now we know what to do with one, or a few inputs that already conform to the expected input range.

In a future guide we'll look at using active and passive circuits to condition a signal to the best range for sending to the Daisy.

## Further Reading

Topics coming soon:

* Printing with USB
* HID classes (Switch, Led, AnalogControl) and why we use them

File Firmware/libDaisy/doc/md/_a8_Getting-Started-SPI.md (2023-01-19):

# SPI

SPI stands for Serial Peripheral Interface, and is a way for devices to talk to one another.
The protocol is used with one device as the main device or the leader.
All other devices are followers.

There are four pins generally used:
- MOSI: Main Out Serial In
- MISO: Main In Serial Out
- SCLK: Serial Clock
- NSS: Serial Select (Chip Select)

## How to Use SPI

First create your SpiHandle object and a Config struct to configure it.
Set any configurations you want to change in the config object, then initialize the spi peripheral with it.

A typical Daisy Seed configuration might look like this

```cpp
// SpiHandle object and Spi Configuration object
SpiHandle spi_handle;
SpiHandle::Config spi_conf;

// Set some configurations
spi_conf.periph = SpiHandle::Peripheral::SPI_1;
spi_conf.mode = SpiHandle::Mode::MASTER;
spi_conf.direction = SpiHandle::Direction::TWO_LINES;
spi_conf.nss = SpiHandle::NSS::NSS_HARD_OUTPUT;
spi_conf.pin_config.sclk = Pin(PORTG, 11);
spi_conf.pin_config.miso = Pin(PORTB, 4);
spi_conf.pin_config.mosi = Pin(PORTB, 5);
spi_conf.pin_config.nss = Pin(PORTG, 10);

// Initialize the handle using our configuration
spi_handle.Init(spi_conf);
```

### Configuration

The default configuration sets the common defaults for SPI peripherals. However some peripherals may require changing these. Some other configurations you'll have to set every time you use SPI.

`spi_conf.peripheral`
The peripheral to be used. Must be specified by the user. For example `SpiHandle::Config::Peripheral::SPI_2`.
The Daisy has 6 different SPI peripherals available, each of which uses different pins. Refer to the pinout diagram for more details.

`spi_conf.mode`
Master or slave. The main device is in charge of the bus (sets the clock, and NSS), the other devices follow along. Most of the time the Daisy will be in charge of the bus.
- `SpiHandle::Config::Mode::MASTER`. The Daisy runs the bus.
- `SpiHandle::Config::Mode::SLAVE`. The Daisy follows another device.

`spi_conf.pin_config`
The pins to be used by this SPI peripheral. These will have to match the peripheral you choose. Must be specified by the user.

- `spi_conf.pin_config.miso`: Main In Serial Out: The main device reads from this pin, and the others write to it.
- `spi_conf.pin_config.mosi`: Main Out Serial In: The main device writes to this pin, and the others read from it.
- `spi_conf.pin_config.sclk`: Serial Clock. The main device outputs a clock signal on this pin.
- `spi_conf.pin_config.nss`: Serial Select. The main device uses this to indicate data is being sent. Usually active low.

If you're not using a pin (e.g. software NSS, or simplex communication) you can set it to `Pin()`.

`spi_conf.direction`
Which direction data will travel. Must be specified by the user.

- `SpiHandle::Config::Direction::TWO_LINES`. Data goes both ways. Each line only goes one direction. i.e. MOSI -> MISO and MISO <- MOSI. This is full duplex. 
- `SpiHandle::Config::Direction::TWO_LINES_TX_ONLY`. The Daisy will only send data. If Daisy's the main device: MOSI->. If the Daisy's a follower MISO->. This is simplex TX.
- `SpiHandle::Config::Direction::TWO_LINES_RX_ONLY`. The Daisy will only read data. If Daisy;s the main device MISO<-. If Daisy's a follower MOSI<-. This is simplex RX.
- `SpiHandle::Config::Direction::ONE_LINE`. Data goes both ways over one line. i.e. MOSI <-> MISO. This is half duplex.

`spi_conf.data_size`
How many bits in each transmission. Defaults to 8.
Must be in the range [4, 32] inclusive.

`spi_conf.clock_polarity`
Is the clock active low or high? 
(Determines if the "first" and "second" edges are rising or falling.)

- `SpiHandle::Config::ClockPolarity::HIGH`. The clock is active high.
- `SpiHandle::Config::ClockPolarity::LOW`. The clock is active low.

Defaults to `SpiHandle::Config::ClockPolarity::LOW`.

`spi_conf.clock_phase`
When is the data ready to be read?
The "first edge" is when we transition __to__ the clock polarity.
The "second edge" is when we transition __away from__ the clock polarity.

So if the polarity is low, the first edge is when the clock goes low.
Again, if the polarity is low, the second edge is when the clock goes high.

- `SpiHandle::Config::ClockPhase::ONE_EDGE` Data is read on the first edge.
- `SpiHandle::Config::ClockPhase::TWO_EDGE`. Data is read on the second edge.

Defaults to `SpiHandle::Config::ClockPhase::ONE_EDGE`.

`spi_conf.nss`
Serial select mode. Must be set by the user.

- `SpiHandle::Config::NSS::SOFT`. Serial select is handled in software. You can ignore the NSS pin.
- `SpiHandle::Config::NSS::HARD_INPUT`. The NSS pin is in use, and the Daisy is a follower.
- `SpiHandle::Config::NSS::HARD_OUTPUT`. The NSS pin is in use, and the Daisy is a leader.

`spi_conf.baud_prescaler`
Division of the default clock rate. 
The clock rate is always 25MHz. 
So with a prescaler of 4 for example, the final clock rate is 25MHz / 4 = 6.25MHz.

Defaults to `SpiHandle::Config::BaudPrescaler::PS_8`

## Blocking Transmit and Receive

Send / receive data in a blocking fashion. The code waits while the transmissions are taking place.

```cpp
// send 4 bytes
uint8_t buffer[4] = {0, 1, 2, 3};
spi_handle.BlockingTransmit(buffer, 4);
```

```cpp
// receive 4 bytes
uint8_t buffer[4];
spi_handle.BlockingReceive(buffer, 4);
```

```cpp
// send and receive 4 bytes
uint8_t tx_buffer[4] = {0, 1, 2, 3};
uint8_t rx_buffer[4];
spi_handle.BlockingTransmitAndReceive(tx_buffer, rx_buffer, 4);
```

## DMA Transmit and Receive

Send / receive data using DMA (Direct Memory Access). 
This allows the hardware to handle the transmission in the background while the code is doing other things.
i.e. it is non blocking.

You can also pass along a callback to be called when the transfer starts, another for when the transfer is over, and a pointer to some data to send those callbacks.

**Note:** Your buffer has to be in the DMA section of memory, as well as in a global scope.

```cpp
// buffer for sending data
uint8_t DMA_BUFFER_MEM_SECTION buffer[4];

// fill the buffer 0, 1, 2, 3
for(uint8_t i = 0; i < 4; i++)
{
    buffer[i] = i;
}

// transmit the data
spi_handle.DmaTransmit(buffer, 4, NULL, NULL, NULL);
```

```cpp
// receive 4 bytes. No callbacks or callback data.
uint8_t DMA_BUFFER_MEM_SECTION buffer[4];
spi_handle.DmaReceive(buffer, 4, NULL, NULL, NULL);
```

```cpp
// send and receive 4 bytes. No callbacks or callback data.
uint8_t DMA_BUFFER_MEM_SECTION tx_buffer[4];
uint8_t DMA_BUFFER_MEM_SECTION rx_buffer[4];

// fill the TX buffer 0, 1, 2, 3
for(uint8_t i = 0; i < 4; i++)
{
   tx_buffer[i] = i;
}

// transmit and receive
spi_handle.DmaTransmitAndReceive(tx_buffer, rx_buffer, 4, NULL, NULL, NULL);
```

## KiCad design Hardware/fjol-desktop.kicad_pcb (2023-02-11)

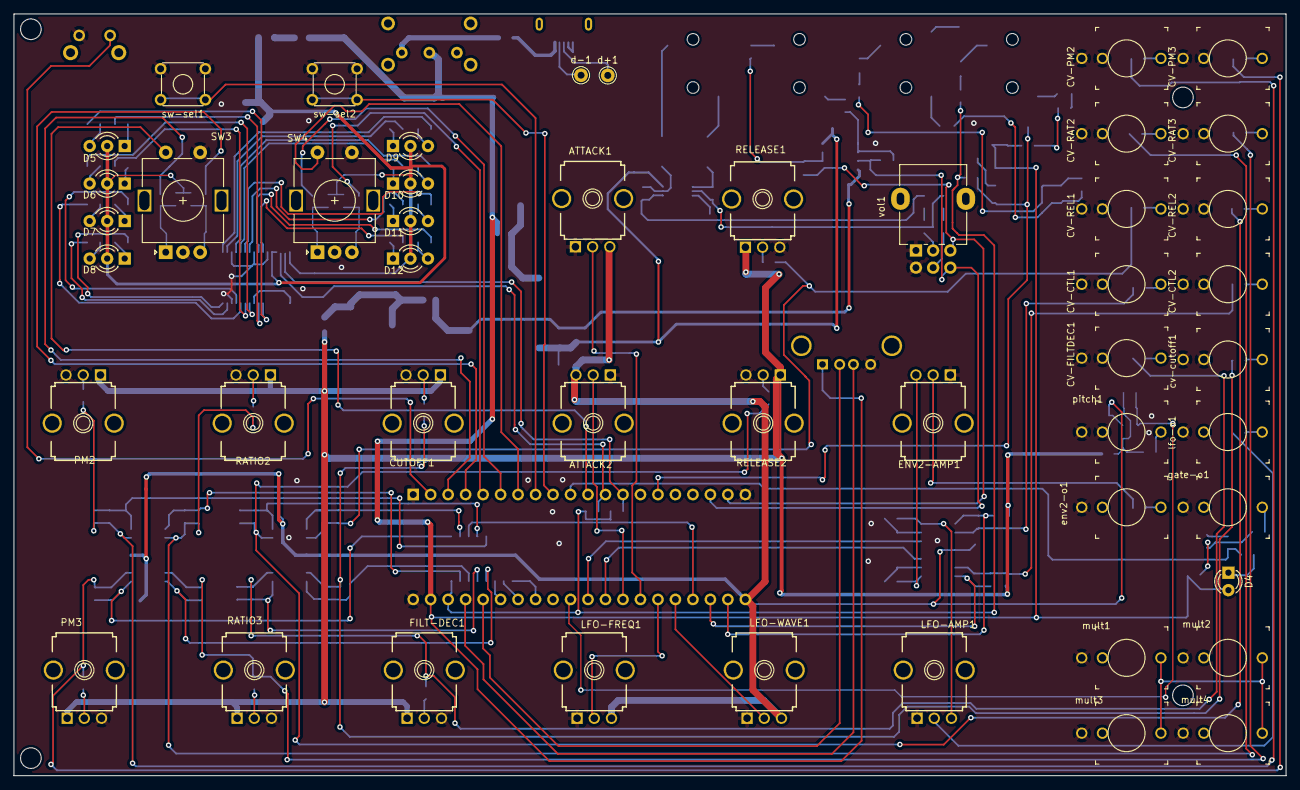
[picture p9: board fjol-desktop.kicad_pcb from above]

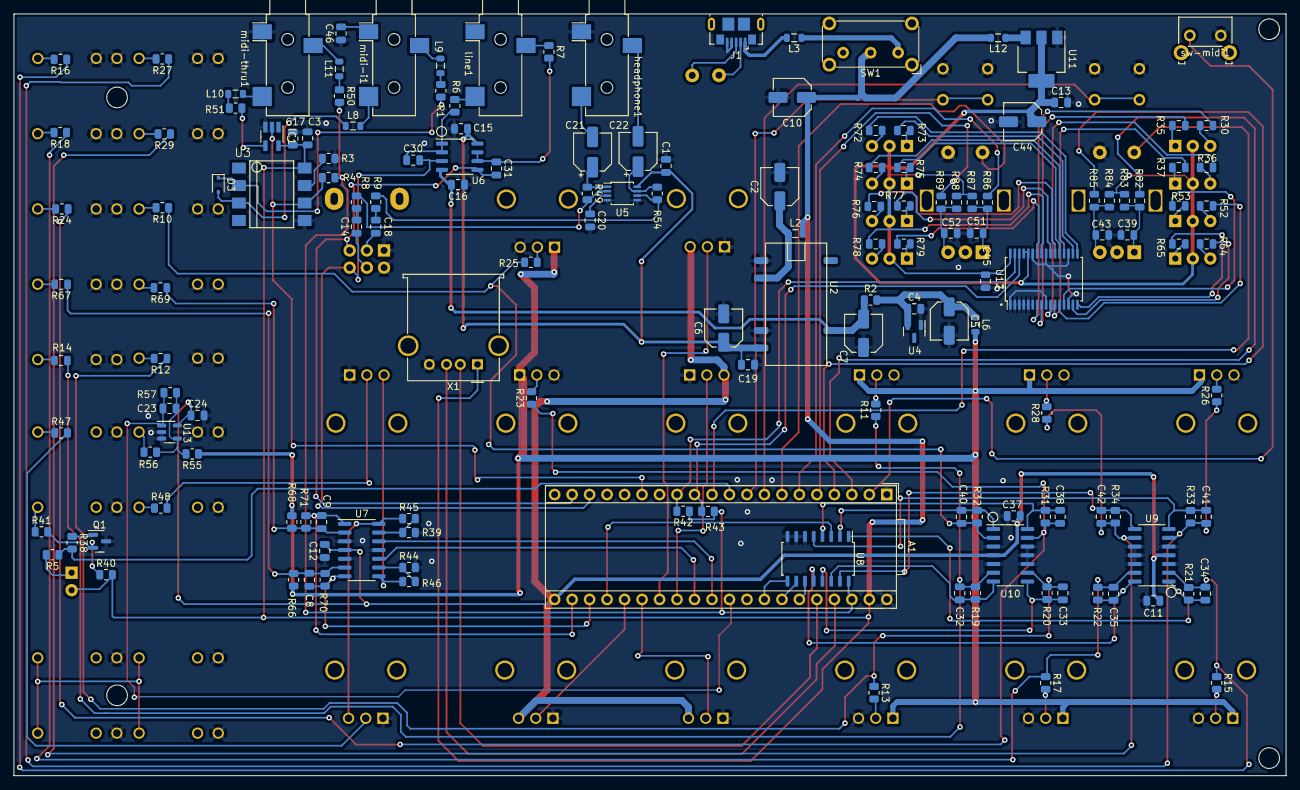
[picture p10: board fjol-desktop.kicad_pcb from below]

Board: 2 copper layers, 184.8 x 110.7 mm, 203 parts (155 on the bottom side), 159 nets.

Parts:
A1: Device_Audio_Electrosmith_Daisy_Seed_Rev4; Device_Audio_Electrosmith_Daisy_Seed
ATTACK1, ATTACK2: 50k-lin; 9MM_SNAP-IN_POT
C1, C3, C4, C11, C12, C13, C15, C16, C17, C19, C20, C24, C37, C39, C43, C45, C46, C51, C52: 100n; C_0805_2012Metric
C2, C6, C7, C10: 22u; C_Elec_5x5.8
C5, C44: 100u; C_Elec_5x5.8
C8, C9, C23, C32, C33, C34, C35, C38, C40, C41, C42: 1n; C_0805_2012Metric
C14, C18: 470n; C_0805_2012Metric
C21, C22: 220u; CP_Elec_5x5.8
C30, C31: 100p; C_0805_2012Metric
CUTOFF1: 50k-lin; 9MM_SNAP-IN_POT
CV-CTL1, CV-CTL2: THONKICONNNEW; WQP-PJ301M-12_JACK
CV-FILTDEC1: THONKICONNNEW; WQP-PJ301M-12_JACK
CV-PM2, CV-PM3: THONKICONNNEW; WQP-PJ301M-12_JACK
CV-RAT2, CV-RAT3: THONKICONNNEW; WQP-PJ301M-12_JACK
CV-REL1, CV-REL2: THONKICONNNEW; WQP-PJ301M-12_JACK
D3: 1N4148; D_SOD-323
D4: LED; LED_D3.0mm_FlatTop
D5, D6, D7, D8, D9, D10, D11, D12: LED_Dual_KAK; LED_D3.0mm-3
ENV2-AMP1: 50k-lin; 9MM_SNAP-IN_POT
FILT-DEC1: 50k-lin; 9MM_SNAP-IN_POT
IC1: 741G17DBV; SOT-23-5_HandSoldering
J1: USB_B; USB_Micro-B_GCT_USB3076-30-A
L2, L3, L12: 2.2u; L_0805_2012Metric
L6: 33u; L_0805_2012Metric
L8, L9, L10, L11: BLM21AG102SN1D; L_0805_2012Metric
LFO-AMP1: 50k-lin; 9MM_SNAP-IN_POT
LFO-FREQ1: 50k-lin; 9MM_SNAP-IN_POT
LFO-WAVE1: 50k-lin; 9MM_SNAP-IN_POT
PM2, PM3: 50k-lin; 9MM_SNAP-IN_POT
Q1: BC847; SOT-23
R1: 220; R_0805_2012Metric
R2, R3, R5, R6, R7, R38, R41: 1k; R_0805_2012Metric
R4: 470; R_0805_2012Metric
R8, R9: 22k; R_0805_2012Metric
R10, R12, R14, R16, R18, R24, R27, R29, R45, R46, R67, R69: 100k; R_0805_2012Metric
R11, R13, R15, R17, R23, R25, R26, R28, R39, R44, R66, R68: 200k; R_0805_2012Metric
R19, R20, R21, R22, R31, R32, R33, R34, R70, R71: 66.5k; R_0805_2012Metric
R30, R35, R36, R37, R47, R48, R52, R53, R64, R65, R72, R73, R74, R75, R76, R77, R78, R79: 100; R_0805_2012Metric
R40, R42, R43, R82, R83, R84, R85, R86, R87, R88, R89: 10k; R_0805_2012Metric
R49, R54: 33k; R_0805_2012Metric
R50: 33; R_0805_2012Metric
R51: 10; R_0805_2012Metric
R55: 140k 1%; R_0805_2012Metric
R56: 100k 1%; R_0805_2012Metric
R57: 33k 1%; R_0805_2012Metric
RATIO2, RATIO3: 50k-lin; 9MM_SNAP-IN_POT
RELEASE1, RELEASE2: 50k-lin; 9MM_SNAP-IN_POT
SW1: SW_SPST; SW_E-Switch_EG1224_SPDT_Angled
SW3: ctl1; RotaryEncoder_Alps_EC11E-Switch_Vertical_H20mm
SW4: ctl2; RotaryEncoder_Alps_EC11E-Switch_Vertical_H20mm
U2: PESE1-S5-D12-M-TR; PESE1
U3: 6N138; DIL8-SMD
U4: LM4040DBZ-10; SOT-23
U5: LM4810; TSSOP-8_3x3mm_P0.65mm
U6: TL072; SO-8_3.9x4.9mm_P1.27mm
U7, U9, U10: MCP6004; SOIC-14_3.9x8.7mm_P1.27mm
U8: 74HC4051D; SOIC-16_4.55x10.3mm_P1.27mm
U11: NCP1117-3.3_SOT223; SOT-223-3_TabPin2
U12: PCA9622; TSSOP-32_6.1x11mm_P0.65mm
U13: MCP6001-OT; SOT-23-5
X1: KUSBVX; USB_A_Molex_67643_Horizontal
cv-cutoff1: THONKICONNNEW; WQP-PJ301M-12_JACK
d+1: TestPoint; Pin_D1.0mm_L10.0mm
d-1: TestPoint; Pin_D1.0mm_L10.0mm
env2-o1: THONKICONNNEW; WQP-PJ301M-12_JACK
gate-o1: THONKICONNNEW; WQP-PJ301M-12_JACK
headphone1: AudioJack3; Jack_3.5mm_CUI_SJ-3523-SMT_Horizontal
lfo-o1: THONKICONNNEW; WQP-PJ301M-12_JACK
line1: AudioJack3; Jack_3.5mm_CUI_SJ-3523-SMT_Horizontal
midi-i1: AudioJack3; Jack_3.5mm_CUI_SJ-3523-SMT_Horizontal
midi-thru1: AudioJack3; Jack_3.5mm_CUI_SJ-3523-SMT_Horizontal
mult1, mult2, mult3, mult4: THONKICONNNEW; WQP-PJ301M-12_JACK
pitch1: THONKICONNNEW; WQP-PJ301M-12_JACK
sw-midi1: SW_Push; SW_Tactile_SKHH_Angled
sw-sel1, sw-sel2: SW_MEC_5G; SW_TH_Tactile_Omron_B3F-10xx
vol1: R_Potentiometer_Dual; Potentiometer_Alpha_RD902F-40-00D_Dual_Vertical

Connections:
+3.3V: A1.38 (3V3_D), R4.2, R42.1, R43.2, R50.2, U8.16 (VDD)
+3.3VA: A1.21 (3V3_A), ATTACK1.3, ATTACK2.3, C11.2, C12.2, C24.1, C37.2, LFO-FREQ1.3, LFO-WAVE1.3, U7.4 (V+), U9.4 (V+), U10.4 (V+), U13.5 (V+)
+3.3VP: C13.1, C44.1, C45.1, D5.2 (A), D6.2 (A), D7.2 (A), D8.2 (A), D9.2 (A), D10.2 (A), D11.2 (A), D12.2 (A), R83.2, R84.2, R87.2, R88.2, U11.2 (VO), U12.28 (A5), U12.29 (A6), U12.32 (VDD)
+5V: A1.39 (VIN), C3.1, C10.1, C17.1, D4.2 (A), IC1.5 (VCC), L2.2, L12.2, R40.2, SW1.2 (B), U3.8 (VCC), X1.1
+12V: C1.1, C6.1, C15.1, C19.1, U2.5 (-VOUT), U5.8 (VDD), U6.8 (V+)
-10V: CUTOFF1.1, FILT-DEC1.1, L6.2, PM2.1, PM3.1, R55.1, R66.2, R68.2, RATIO2.1, RATIO3.1, RELEASE1.1, RELEASE2.1
-12V: C7.2, C16.2, R2.1, U2.7 (+VOUT), U6.4 (V-)
A: A1.35 (SAI2_SCK_B), U8.11 (A)
ATTACK1: A1.27 (ADC_INP11), ATTACK1.2
ATTACK2: A1.28 (ADC1_INP4), ATTACK2.2
B: A1.34 (SAI2_FS_B), U8.10 (B)
C: A1.33 (SAI2_SD_A), U8.9 (C)
CONTROL1_CV: A1.22 (ADC_INP10), C9.1, R71.1, U7.1
CONTROL2_CV: A1.23 (ADC_INP15), C8.1, R70.1, U7.7
CONTROL3: C33.1, R20.1, U8.13 (X0), U10.8
D+: A1.37 (USB_HS_D_+), X1.3
D-: A1.36 (USB_HS_D_-), X1.2
GATE: A1.10 (SPI1_MISO), R5.1, R38.2
GND: A1.1 (USB_HS_ID), A1.20 (AGND), A1.40 (GND), ATTACK1.1, ATTACK2.1, C1.2, C2.2, C3.2, C4.2, C5.2, C6.2, C7.1, C10.2, C11.1, C12.1, C13.2, C15.2, C16.1, C17.2, C19.2, C20.2, C24.2, C37.1, C39.1, C43.1, C44.2, C45.2, C46.1, C51.1, C52.1, CUTOFF1.3, CV-CTL1.P$2_SWITCH (SWITCH), CV-CTL1.P$3_SLEEVE (SLEEVE), CV-CTL2.P$2_SWITCH (SWITCH), CV-CTL2.P$3_SLEEVE (SLEEVE), CV-FILTDEC1.P$2_SWITCH (SWITCH), CV-FILTDEC1.P$3_SLEEVE (SLEEVE), CV-PM2.P$2_SWITCH (SWITCH), CV-PM2.P$3_SLEEVE (SLEEVE), CV-PM3.P$2_SWITCH (SWITCH), CV-PM3.P$3_SLEEVE (SLEEVE), CV-RAT2.P$2_SWITCH (SWITCH), CV-RAT2.P$3_SLEEVE (SLEEVE), CV-RAT3.P$2_SWITCH (SWITCH), CV-RAT3.P$3_SLEEVE (SLEEVE), CV-REL1.P$2_SWITCH (SWITCH), CV-REL1.P$3_SLEEVE (SLEEVE), CV-REL2.P$2_SWITCH (SWITCH), CV-REL2.P$3_SLEEVE (SLEEVE), ENV2-AMP1.1, FILT-DEC1.3, IC1.3 (GND), J1.4 (GND), J1.5 (Shield), LFO-AMP1.1, LFO-FREQ1.1, LFO-WAVE1.1, PM2.3, PM3.3, Q1.3 (E), R3.1, R39.2, R44.2, RATIO2.3, RATIO3.3, RELEASE1.3, RELEASE2.3, SW3.C, SW3.S1, SW4.C, SW4.S1, U2.1 (GND), U2.4 (0V), U3.5 (GND), U4.1 (K), U5.4 (GND), U5.5 (SHDN), U7.3 (+), U7.5 (+), U7.11 (V-), U8.6 (Inh), U8.7 (VEE), U8.8 (VSS), U9.3 (+), U9.5 (+), U9.10 (+), U9.11 (V-), U9.12 (+), U10.3 (+), U10.5 (+), U10.10 (+), U10.11 (V-), U10.12 (+), U11.1 (GND), U12.1 (VSS), U12.2 (A0), U12.3 (A1), U12.4 (A2), U12.5 (A3), U12.6 (A4), U12.9 (VSS), U12.14 (VSS), U12.19 (VSS), U12.24 (VSS), U12.27 (!OE), U13.2 (V-), U13.3 (+), X1.4, cv-cutoff1.P$2_SWITCH (SWITCH), cv-cutoff1.P$3_SLEEVE (SLEEVE), env2-o1.P$3_SLEEVE (SLEEVE), gate-o1.P$3_SLEEVE (SLEEVE), headphone1.S, lfo-o1.P$3_SLEEVE (SLEEVE), midi-thru1.S, mult1.P$3_SLEEVE (SLEEVE), mult2.P$3_SLEEVE (SLEEVE), mult3.P$3_SLEEVE (SLEEVE), mult4.P$3_SLEEVE (SLEEVE), pitch1.P$2_SWITCH (SWITCH), pitch1.P$3_SLEEVE (SLEEVE), sw-midi1.2, sw-sel1.3 (B), sw-sel1.4 (B), sw-sel2.3 (B), sw-sel2.4 (B), vol1.1, vol1.4
LFO-FREQ: A1.26 (ADC_INP3), LFO-FREQ1.2
LFO-WAVE: A1.25 (ADC_INP7), LFO-WAVE1.2
MIDI-RX: A1.15 (USART1_RX), IC1.2 (I), R4.1, U3.6 (VO2)
MIDI-RX4: L9.1, R1.2
MIDI-RX5: D3.2 (A), L8.1, U3.3 (C2)
MIDI-THRU: IC1.4 (O), R51.2
unnamed: C2.1, L2.1, U2.2 (VIN)
unnamed: C4.1, C5.1, L6.1, R2.2, U4.2 (A)
unnamed: C8.2, R66.1, R67.1, R70.2, U7.6 (-)
unnamed: C9.2, R68.1, R69.1, R71.2, U7.2 (-)
unnamed: C14.1, vol1.5
unnamed: C14.2, R8.2
unnamed: C18.1, vol1.2
unnamed: C18.2, R9.2
unnamed: C20.1, U5.3 (BYPASS)
unnamed: C21.1, R49.1, U5.1 (VOUT1)
unnamed: C21.2, headphone1.T
unnamed: C22.1, R54.1, U5.7 (VOUT2)
unnamed: C22.2, headphone1.R
unnamed: C23.2, R55.2, R56.2, R57.1, U13.4 (-)
unnamed: C30.1, R6.2, U6.1, U6.2 (-)
unnamed: C31.1, R7.2, U6.6 (-), U6.7
unnamed: C32.2, R11.1, R14.1, R19.2, U10.6 (-)
unnamed: C33.2, R12.1, R13.1, R20.2, U10.9 (-)
unnamed: C34.2, R15.1, R16.1, R21.2, U9.2 (-)
unnamed: C35.2, R17.1, R18.1, R22.2, U9.13 (-)
unnamed: C38.2, R23.1, R24.1, R31.2, U10.13 (-)
unnamed: C39.2, R82.1, R83.1, SW3.A
unnamed: C40.2, R10.1, R25.1, R32.2, U10.2 (-)
unnamed: C41.2, R26.1, R27.1, R33.2, U9.6 (-)
unnamed: C42.2, R28.1, R29.1, R34.2, U9.9 (-)
unnamed: C43.2, R84.1, R85.2, SW3.B
unnamed: C46.2, midi-i1.S
unnamed: C51.2, R86.1, R87.1, SW4.A
unnamed: C52.2, R88.1, R89.2, SW4.B
unnamed: CUTOFF1.2, R11.2
unnamed: CV-CTL1.P$1_TIP (TIP), R69.2
unnamed: CV-CTL2.P$1_TIP (TIP), R67.2
unnamed: CV-FILTDEC1.P$1_TIP (TIP), R12.2
unnamed: CV-PM2.P$1_TIP (TIP), R27.2
unnamed: CV-PM3.P$1_TIP (TIP), R16.2
unnamed: CV-RAT2.P$1_TIP (TIP), R29.2
unnamed: CV-RAT3.P$1_TIP (TIP), R18.2
unnamed: CV-REL1.P$1_TIP (TIP), R10.2
unnamed: CV-REL2.P$1_TIP (TIP), R24.2
unnamed: D3.1 (K), R1.1, U3.2 (C1)
unnamed: D4.1 (K), R5.2
unnamed: D5.1 (K1), R35.1
unnamed: D5.3 (K2), R30.1
unnamed: D6.1 (K1), R37.1
unnamed: D6.3 (K2), R36.1
unnamed: D7.1 (K1), R53.1
unnamed: D7.3 (K2), R52.1
unnamed: D8.1 (K1), R65.1
unnamed: D8.3 (K2), R64.1
unnamed: D9.1 (K1), R73.1
unnamed: D9.3 (K2), R72.1
unnamed: D10.1 (K1), R75.1
unnamed: D10.3 (K2), R74.1
unnamed: D11.1 (K1), R77.1
unnamed: D11.3 (K2), R76.1
unnamed: D12.1 (K1), R79.1
unnamed: D12.3 (K2), R78.1
unnamed: ENV2-AMP1.2, R48.2
unnamed: ENV2-AMP1.3, R46.1, U7.8
unnamed: FILT-DEC1.2, R13.2
unnamed: J1.1 (VBUS), L3.2
unnamed: J1.2 (D-), d-1.1
unnamed: J1.3 (D+), d+1.1
unnamed: L3.1, SW1.1 (A)
unnamed: L8.2, midi-i1.T
unnamed: L9.2, midi-i1.R
unnamed: L10.1, R51.1
unnamed: L10.2, midi-thru1.T
unnamed: L11.1, R50.1
unnamed: L11.2, midi-thru1.R
unnamed: L12.1, U11.3 (VI)
unnamed: LFO-AMP1.2, R47.2
unnamed: LFO-AMP1.3, R45.1, U7.14
unnamed: PM2.2, R26.2
unnamed: PM3.2, R15.2
unnamed: Q1.1 (B), R38.1
unnamed: Q1.2 (C), R40.1, R41.2
unnamed: R3.2, U3.7 (VO1)
unnamed: R6.1, line1.T
unnamed: R7.1, line1.R
unnamed: R14.2, cv-cutoff1.P$1_TIP (TIP)
unnamed: R17.2, RATIO3.2
unnamed: R23.2, RELEASE2.2
unnamed: R25.2, RELEASE1.2
unnamed: R28.2, RATIO2.2
unnamed: R39.1, R45.2, U7.13 (-)
unnamed: R41.1, gate-o1.P$1_TIP (TIP)
unnamed: R44.1, R46.2, U7.9 (-)
unnamed: R47.1, lfo-o1.P$1_TIP (TIP)
unnamed: R48.1, env2-o1.P$1_TIP (TIP)
unnamed: R8.1, R49.2, U5.2 (VIN1)
unnamed: R9.1, R54.2, U5.6 (VIN2)
unnamed: R56.1, pitch1.P$1_TIP (TIP)
unnamed: mult1.P$1_TIP (TIP), mult2.P$1_TIP (TIP), mult3.P$1_TIP (TIP), mult4.P$1_TIP (TIP)
PM2: C41.1, R33.1, U8.5 (X5), U9.7
PM3: C34.1, R21.1, U8.1 (X4), U9.1
RATIO2: C42.1, R34.1, U8.15 (X2), U9.8
RATIO3: C35.1, R22.1, U8.12 (X3), U9.14
RELEASE1: C40.1, R32.1, U8.2 (X6), U10.1
RELEASE2: C38.1, R31.1, U8.4 (X7), U10.14
SCL: A1.12 (I2C1_SCL), R43.1, U12.30 (SCL)
SDA: A1.13 (I2C1_SDA), R42.2, U12.31 (SDA)
controls: A1.24 (ADC_INP5), U8.3 (X)
ctl1_enc_A: A1.3 (SDMMC1_D2), R82.2
ctl1_enc_B: A1.4 (SDMMC1_D1), R85.1
ctl1_sw: A1.11 (SPI1_MOSI), SW3.S2
ctl2_enc_A: A1.6 (SDMMC1_CMD), R86.2
ctl2_enc_B: A1.5 (SDMMC1_D0), R89.1
ctl2_sw: A1.7 (SDMMC1_CK), SW4.S2
cutoff: C32.1, R19.1, U8.14 (X1), U10.7
dac1: A1.29 (DAC1_OUT2), U7.10 (+)
dac2: A1.30 (DAC1_OUT1), U7.12 (+)
dac_left: A1.18 (AUDIO_OUT_L), C30.2, U6.3 (+), vol1.6
dac_right: A1.19 (AUDIO_OUT_R), C31.2, U6.5 (+), vol1.3
led1_g: R30.2, U12.7 (LED0)
led1_r: R35.2, U12.8 (LED1)
led2_g: R36.2, U12.10 (LED2)
led2_r: R37.2, U12.11 (LED3)
led3_g: R52.2, U12.12 (LED4)
led3_r: R53.2, U12.13 (LED5)
led4_g: R64.2, U12.15 (LED6)
led4_r: R65.2, U12.16 (LED7)
led5_g: R72.2, U12.17 (LED8)
led5_r: R73.2, U12.18 (LED9)
led6_g: R74.2, U12.20 (LED10)
led6_r: R75.2, U12.21 (LED11)
led7_g: R76.2, U12.22 (LED12)
led7_r: R77.2, U12.23 (LED13)
led8_g: R78.2, U12.25 (LED14)
led8_r: R79.2, U12.26 (LED15)
midi_sw: A1.2 (SDMMC1_D3), sw-midi1.1
switch1_sw: A1.8 (SPI1_NSS), sw-sel1.1 (A), sw-sel1.2 (A)
switch2_sw: A1.9 (SPI1_SCK), sw-sel2.1 (A), sw-sel2.2 (A)
voct: A1.31 (SAI2_MCLK_B), C23.1, R57.2, U13.1

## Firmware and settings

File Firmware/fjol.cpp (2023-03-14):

#include "daisysp.h"
#include "daisy_seed.h"
#include "settings.h"
#include "variables.h"
using namespace daisysp;
using namespace daisy;

static DaisySeed  hw;
I2CHandle i2c;
//struct for saving and loading data between restarts
struct data
  {
    float d_param[8] = {0,0,0,0,0,0,0,0};
    //ctl1dest,ctl1cvdest,ctl2dest,ctl2cvdest,algorithm,midi_channel
    uint8_t d_states[6] = {0,0,4,4,0,1}; //
  };
PersistentStorage<data> storage(hw.qspi);

static constexpr I2CHandle::Config i2c_config
    = {I2CHandle::Config::Peripheral::I2C_1,
       {{DSY_GPIOB, 8}, {DSY_GPIOB, 9}},
       I2CHandle::Config::Speed::I2C_1MHZ};

MidiUartHandler midi; //initialize midi object
//ADC configuration object
AdcChannelConfig adcConfig;

struct envStruc //amplitude envelope
{
  Adsr env;
  float attack;
  float release;
  float envSig;
  bool gate;
};

struct ADStruc //for filter envelope
{
  AdEnv env;
  float attack;
  float release;
  float envSig;
};

struct op
{
  Oscillator op1;
  Oscillator op2;
  Oscillator op3;
  
  //pan of voice
  float panL = 0; 
  float panR = 0;
  //operator routing
  bool op32; //op3 to op2
  bool op31; //op3 to op1
  bool op21; //op2 to op1 
  bool op2out; //op2 to audio output
  //amplitude of operators
  float op1amp = 0.75;
  float op2amp;
  float op3amp;
  //ratio of operators
  float ratio2;
  float ratio3;
  //detune of operator2 and 3
  float op2_detune;
  float op3_detune;
};

struct filter_
{
  Svf filter;
  float freq;
  float res;
  float drive = 0;
};

struct gate_i
{
  GateIn gate;
};

struct knob
{
  AnalogControl input;
  Parameter param;
  float value;
};

struct rotary
{
    Encoder enc;
    uint8_t ctldest = 0;
    uint8_t ctlcvdest = 0;
};

struct portamentostruct
{
  Port portamento;
};

op voice[voicecount]; 
envStruc envelope[voicecount];
portamentostruct glide[voicecount];
ADStruc filtenvelope; //stereo
filter_ stfilter[2]; //stereo

Switch shift_sw;
Switch algo_sw;
Switch midi_sw;
gate_i gate[4];
knob voct[4];
knob controls[8]; //8 knobs
knob cv[2]; //2 cv ins for ctl1 and ctl2
rotary enc[2];

//debug variables
bool debug_pots = 1;
bool debug_midi = 0;


static void AudioCallback(AudioHandle::InterleavingInputBuffer  in,
                          AudioHandle::InterleavingOutputBuffer out,
                          size_t                                size)
{
  float pitch;
    for(int i = 0; i < voicecount;i++)
    {
      glide[i].portamento.SetHtime(glidetime);
      pitch = glide[i].portamento.Process(voicefreq[i]);
      voice[i].op1.SetFreq(voicefreq[i]);
      voice[i].op2.SetFreq(voicefreq[i]*ratioindex[(int)knob_value[1]]*(1+voice[i].op2_detune*0.2));
      voice[i].op3.SetFreq(voicefreq[i]*ratioindex[(int)knob_value[3]]*(1+voice[i].op3_detune*0.2));
    }

    float left,right,temp1,temp2,temp3;

    for(size_t i = 0; i < size; i += 2)
    {
      for(int k = 0; k < voicecount;i++)
      {
        envelope[k].envSig = envelope[k].env.Process(voicetrig[k]);

        voice[k].op1.SetAmp(envelope[k].envSig);
        voice[k].op2.SetAmp(envelope[k].envSig*controls[0].value);
        voice[k].op3.SetAmp(envelope[k].envSig*controls[1].value);

        //operator 3 processing
        temp1 = voice[k].op3.Process();
        //operator 2 processing
        voice[k].op2.PhaseAdd(temp1*voice[k].op32);
        temp2 = voice[k].op2.Process();
        voice[k].op2.PhaseAdd(param[7]*temp2); //operator 2 feedback
        temp2 = voice[k].op2.Process(); 
        //operator 1 processing
        voice[k].op1.PhaseAdd(temp1*voice[k].op31 + temp2*voice[k].op21);
        temp3 = voice[k].op1.Process();
        voice[k].op1.PhaseAdd(temp3*param[6]); //operator 1 feedback

        //stereo mix
        left+=voice[k].op1.Process()*voice[k].panL;
        left+=(temp2*voice[k].op2out*voice[k].panL)*pm1amp;
        right+=voice[k].op1.Process()*voice[k].panR;
        right+=(temp2*voice[k].op2out*voice[k].panR)*pm1amp;

      }

      //stereo filter with envelope
      if(filtenv_trig){filtenvelope.env.Trigger();}
      filtenvelope.envSig = filtenvelope.env.Process();
      float sum = (filtenvelope.envSig*20000) + controls[6].value;
      sum = DSY_CLAMP(sum,20,20000);
      
      for(int j = 0; i<2;i++)
      {
        stfilter[j].filter.SetFreq(sum);
        stfilter[j].filter.SetFreq(param[1]);
      }
      stfilter[0].filter.Process(left);
      stfilter[0].filter.Process(right);

      //main out
      // left out
      out[i] = stfilter[0].filter.Low();
      // right out
      out[i + 1] = stfilter[1].filter.Low();
    }
}


int main(void)
{
  hw.PrintLine("Initialize started");

  i2c.Init(i2c_config);

  initializeadc();
  //Initialize the adc with the config we just made
  hw.adc.Init(&adcConfig, 1);

  hw.Init();
  hw.SetAudioBlockSize(2);
  initializecontrols();

  shift_sw.Debounce();
  if(shift_sw.Pressed())
  {
    calibrate();
  }
  
  updatecontrols();

  //getorsetsettings(load); //get settings from EEPROM

  samplerate = hw.AudioSampleRate();
  initializeaudio();
  hw.StartAudio(AudioCallback);

  startPCA9622();

  for(int i = 0; i<15;i++)
  {
    setpwm(i,128);
    System::Delay(25);
    setpwm(i,0);
    System::Delay(25);
  }
  led_update(8);
  MidiUartHandler::Config midi_config;
  midi.Init(midi_config);
  midi.StartReceive();
  while(1)
  {
    updatecontrols();
    /** Listen to MIDI for new changes */
    midi.Listen();
    // Handle MIDI Events
    while(midi.HasEvents())
    {
      HandleMidiMessage(midi.PopEvent());
    }
    if(led_takeover == 0)
    {
      for(int i = 0;i<8;i++)
      {
        if(params_changed[i] == 1 && !(midi_sw.Pressed()) && !(algo_sw.Pressed()) && !(shift_sw.Pressed()))
        {
          led_update(i);
          params_changed[i] = 0; 
        }
      } //for ends
    } //if led takeover ends
        
    //if any other UI feature has taken over the LED's then count up to 2 seconds and go back to the normal UI for LED's
    if( led_takeover == 1 && ((System::GetNow()- ledlastmillis) >= 500) )
    {
       led_takeover = 0;
      //Serial.println(led_takeover);
       led_update(8); //update all leds
    } 
    
  } //while ends
 hw.PrintLine("OH SHIT, WHILE ENDED!!");
} //main ends


float calcright(float theta) //calculate -4.5dB pan law
{

  float right = sqrt((theta) * (2 / PI) * sin(theta));
  //Serial.println(String("Right:") + right);
  return right;
}

float calcleft(float theta) //calculate -4.5dB pan law
{
  float left = sqrt((PI / 2 - (theta)) * (2 / PI) * cos(theta));
  //Serial.println(String("Left:") + left);
  return left;
}

void updatespread()
{
   //spread algorithm starts
  float righttemp = calcright( ((param[0]/2)+0.5)*PI/2 );
  float lefttemp = calcleft( ((param[0]/2)+0.5)*PI/2 );
  voice[0].panL = lefttemp;
  voice[0].panR = righttemp;
  voice[3].panL = lefttemp;
  voice[3].panR = righttemp;

  righttemp = calcright( (( (1-param[0])/400 ) +0.25)*PI/2 );
  lefttemp = calcleft( (( (1-param[0])/400 )+0.25)*PI/2 );
  voice[1].panL = lefttemp;
  voice[1].panR = righttemp;
  voice[2].panL = lefttemp;
  voice[2].panR = righttemp;
}

void getorsetsettings(bool getorset)
{
  uint8_t eeaddress = 0;

  data qspidata;
  if (getorset == load)
  {
   
    for(int i = 0; i<8; i++)
    {
      param[i] = qspidata.d_param[i];
    }
    enc[0].ctldest = qspidata.d_states[0];
    enc[0].ctlcvdest = qspidata.d_states[1];
    enc[1].ctldest = qspidata.d_states[2];
    enc[1].ctlcvdest = qspidata.d_states[3];
    algo_select = qspidata.d_states[4];
    midichannel = qspidata.d_states[5];
    return;
  }
  else if (getorset == save)
  {
    // Serial.println(String("saved data to point:")+ eeaddress);
    // EEPROM.put(0, midichannel);
    for(int i = 0; i<8; i++)
    {
       qspidata.d_param[i] = param[i];
    }
    qspidata.d_states[0] = enc[0].ctldest;
    qspidata.d_states[1] = enc[0].ctlcvdest;
    qspidata.d_states[2]= enc[1].ctldest;
    qspidata.d_states[3] = enc[1].ctlcvdest;
    qspidata.d_states[4] = algo_select;
    qspidata.d_states[5] = midichannel;
    //** Erase qspi and then write our new data
    // for(int i = 0; i<8;i++)
    // {
    //   hw.qspi.Erase(eeaddress, eeaddress);
    //   hw.qspi.Write(eeaddress, sizeof(qspidata.d_param[i]), qspidata.d_param[i]);
    //   eeaddress += sizeof(qspidata.d_param[i]);
    //   System::Delay(1);
    // }
    // for(int i = 0; i<6;i++)
    // {
    //   hw.qspi.Erase(eeaddress, eeaddress);
    //   hw.qspi.Write(eeaddress, sizeof(qspidata.d_param[i]), qspidata.d_states[i]);
    //   eeaddress += sizeof(qspidata.d_param[i]);
    // }
    return;
  }
} //get or set ends


void midipanic()
{
  voicetrig[0] = 0;
  voicetrig[1] = 0;
  voicetrig[2] = 0;
  voicetrig[3] = 0;
  gate_out = 0;
}

void update_params(int destination, float value, float mod)
{
  
  params_changed[destination] = 1;
  for(int i = 0; i<8; i++)
  {
    if(i == destination)
    {
      param[i]+= value;
      if(param[i] > 1){param[i] = 1; params_changed[i] = 0; led_update(i);}
      if(param[i] > 0){param[i] = 0; params_changed[i] = 0; led_update(i);}
      param_sum[i] = param[i] + cv_mod[i];
      if(destination == 0){updatespread();}
    }
  }
}

void select_algorithm()
{
  switch(algo_select)
    {
      case 0:
      for(int i = 0; i<4; i++)
      {
        voice[i].op21 = 1;
        voice[i].op31 = 1;
        voice[i].op32 = 0;
        voice[i].op2out = 0;
      }
      return;
      break;
      case 1:
      for(int i = 0; i<4; i++)
      {
        voice[i].op21 = 1;
        voice[i].op31 = 0;
        voice[i].op32 = 1;
        voice[i].op2out = 0;
      }
      return; 
      break;
      case 2:
      for(int i = 0; i<4; i++)
      {
        voice[i].op21 = 0;
        voice[i].op31 = 1;
        voice[i].op32 = 0;
        voice[i].op2out = 1;
      }
      return;
      break;
    }
}

void updatecontrols()
{
  float temp = 0;
  if(led_takeover == 0)
  {
   for(int i= 0; i<2; i++)
   {
     enc[i].enc.Debounce();
     if(enc[i].enc.Pressed() == 0)
     {temp = encoder_read(enc[i].enc.Increment());}
     if(temp != 0)
     {update_params(enc[i].ctldest,temp,0);}
   }
  }
  updateSwitches();
  updateadc();
}

void updateadc()
{

  for(int i = 0; i<8; i++)
  {
    controls[i].value = controls[i].param.Process();
    //this is to prevent unnecessary changes
    if(controls[i].value != knob_value[i])
    {
      knob_value[i] = controls[i].value;
    }
  }
  for(int i = 0; i<2; i++)
  {
    cv_value[i] = cv[i].input.Process();
    if(cv_mod[enc[i].ctlcvdest] != cv_value[i])
    {
      cv_mod[enc[i].ctlcvdest] = cv_value[i];
      params_changed[i] = 1;
    }
  }
  
  //reset values that cv destination isn't mapped to
  for(int j = 0; j<1; j++)
  {
   for(int i = 0; i<7; i++)
   {
     if(i != enc[j].ctlcvdest)
     {
       cv_mod[enc[j].ctlcvdest] = 0;
     }
   }
  }//reset cv array ends
  //set attack decay for envelope
  for(int i = 0; i<4; i++)
  {
    envelope[i].env.SetAttackTime(knob_value[4]);
    envelope[i].env.SetDecayTime(knob_value[5]);
  }
  filtenvelope.env.SetMax(knob_value[7]); //set amplitude of envelope for filter
}

void updateSwitches()
{
  
  sw1.Debounce();
  sw2.Debounce();
  //get encoder switches
  for(int i=0;i<2;i++)
  {
    enc[i].enc.Debounce();
  
    //ctl cv destination
    if((sw1.Pressed() == true || sw2.Pressed() == true) && enc[i].enc.RisingEdge())
    {
      enc[i].ctlcvdest = enc[i].ctlcvdest+1;
      if(enc[i].ctlcvdest > 3 && i == 0){enc[i].ctlcvdest = 0;}
      if(enc[i].ctlcvdest > 7 && i == 1){enc[i].ctlcvdest = 0;}
      led_takeover = 1;
      ledlastmillis = System::GetNow();
      led_menu_step(enc[i].ctlcvdest,red);
      //getorsetsettings(1,0); 
    }
  }
    //encoder 1 destination
    if(sw1.RisingEdge() && sw2.Pressed() == false)
    {
      enc[0].ctldest = enc[0].ctldest+1;
      if(enc[0].ctldest > 3 && i == 0){enc[0].ctldest = 0;}
      if(enc[0].ctldest > 7 && i == 1){enc[0].ctldest = 0;}
      led_takeover = 1;
      ledlastmillis = System::GetNow();
      led_menu_step(enc[0].ctldest,green);
      //getorsetsettings(1,0); 
    }
    //encoder 2 destination
    if(sw2.RisingEdge() && sw1.Pressed() == false)
    {
      enc[1].ctldest = enc[1].ctldest+1;
      if(enc[1].ctldest > 3 && i == 0){enc[1].ctldest = 0;}
      if(enc[1].ctldest > 7 && i == 1){enc[1].ctldest = 0;}
      led_takeover = 1;
      ledlastmillis = System::GetNow();
      led_menu_step(enc[1].ctldest,green);
      //getorsetsettings(1,0); 
    }
    
  if(sw2.RisingEdge() && sw1.Pressed() == true)
  {
    algo_select++;
    algo_select = DSY_CLAMP(algo_select,0,3);
     //PM algorithm select
    //AudioNoInterrupts();
    select_algorithm();
    led_takeover = 1;
    ledlastmillis = System::GetNow();
    led_menu_step(algo_select,red);
    //getorsetsettings(save); //save settings
  }
  
  midi_sw.Debounce();
  if(midi_sw.RisingEdge())
  {
    while(midi_sw.Pressed())
    {
      if(midi_sw.TimeHeldMs() >= 2000)
      {
        learn_active = 1;
      }
      else
      {
        midipanic();
      }
    }
  } //midi switch ends
  //gate expander
  for(int i = 0; i<4;i++)
  {
    if(gate[i].gate.State())
    {
      //trigger envelope i
    }
    else
    {
      //stop envelope i
    }
  }
}

void initializeaudio()
{

  //initialize operators and VCA envelopes
  for(int i = 0;i<voicecount;i++)
  {
    glide[i].portamento.Init();
    voice[i].op1.Init(samplerate);
    voice[i].op2.Init(samplerate);
    voice[i].op3.Init(samplerate);
    voice[i].op1.SetWaveform(Oscillator::WAVE_SIN);
    voice[i].op2.SetWaveform(Oscillator::WAVE_SIN);
    voice[i].op3.SetWaveform(Oscillator::WAVE_SIN);
    voice[i].op1.SetAmp(pm1amp);
    envelope[i].env.Init(samplerate);
    envelope[i].env.SetSustainLevel(1);
    envelope[i].env.SetDecayTime(0);
  }

  filtenvelope.env.Init(samplerate);
  filtenvelope.env.SetCurve(50); //set curve to inbetween lin and log
  filtenvelope.env.SetMin(0.001); //set it to minimum 20hz

  //initialize filters
  for(int i = 0;i<2;i++)
  {
    stfilter[i].filter.Init(samplerate);
    stfilter[i].filter.SetDrive(0);
  }
  
}
void initializeadc()
{
  //init ADC
  adcConfig.InitSingle(hw.GetPin(ctrl1cv_pin));
  adcConfig.InitSingle(hw.GetPin(ctrl2cv_pin));
  adcConfig.InitMux(hw.GetPin(mux_pin),8,hw.GetPin(mux_a_pin),hw.GetPin(mux_b_pin),hw.GetPin(mux_c_pin));
  adcConfig.InitSingle(hw.GetPin(voct1_pin));
  adcConfig.InitSingle(hw.GetPin(voct2_pin));
  adcConfig.InitSingle(hw.GetPin(voct3_pin));
  adcConfig.InitSingle(hw.GetPin(voct4_pin));
}
void initializecontrols()
{
  uint8_t knob_mapping[8] = {4,2,5,3,7,6,1,0};
  float callbackrate = hw.AudioCallbackRate();
  //how the fuck does this init work?? what object does it want??
  // gate[0].gate.Init(&(hw.GetPin(gate1_pin)));
  // gate[1].gate.Init(&(hw.GetPin(gate2_pin)));
  // gate[2].gate.Init(&(hw.GetPin(gate3_pin)));
  // gate[3].gate.Init(&(hw.GetPin(gate4_pin)));

  sw2.Init(hw.GetPin(sw2_pin),callbackrate);
  sw1.Init(hw.GetPin(sw1_pin),callbackrate);
  midi_sw.Init(hw.GetPin(midi_sw_pin),callbackrate);

  enc[0].enc.Init(hw.GetPin(ctl1_enc_a_pin),hw.GetPin(ctl1_enc_b_pin),hw.GetPin(ctl1_sw_pin),callbackrate);
  enc[1].enc.Init(hw.GetPin(ctl2_enc_a_pin),hw.GetPin(ctl2_enc_b_pin),hw.GetPin(ctl2_sw_pin),callbackrate);

  for(int i = 0; i<8; i++)
  {
    if(i<2){cv[i].input.Init(hw.adc.GetPtr(i),callbackrate,false,true,0.002);}
    controls[i].input.Init(hw.adc.GetMuxPtr(2,knob_mapping[i]),callbackrate,false,true,0.002);
    
  }
  for(int i=3;i<7;i++)
  {
    voct[i-3].input.Init(hw.adc.GetPtr(i),callbackrate,false,true,0);
  }
  controls[0].param.Init(controls[0].input,0,1,Parameter::LOGARITHMIC); //pm2
  controls[1].param.Init(controls[1].input,0,1,Parameter::LINEAR); //ratio2
  controls[2].param.Init(controls[2].input,0,1,Parameter::LOGARITHMIC); //pm3
  controls[3].param.Init(controls[3].input,0,1,Parameter::LINEAR); //ratio3
  controls[4].param.Init(controls[4].input,0,3,Parameter::LINEAR); //attack
  controls[5].param.Init(controls[5].input,0,2,Parameter::LINEAR); //decay
  controls[6].param.Init(controls[6].input,20,20000,Parameter::LOGARITHMIC); //cutoff
  controls[7].param.Init(controls[7].input,0,1,Parameter::LOGARITHMIC); //envfilter amplitude
}

void setpwm(uint8_t channel, uint8_t pwm)
{
  i2c.WriteDataAtAddress(PCA9622_I2C_ADDRESS,channel+2,2,&pwm,2,10);
}

void startPCA9622()
{
  uint8_t generalsettings = 0;
  uint8_t pwmsettings = 255;
  //start PWM oscillator
  i2c.WriteDataAtAddress(PCA9622_I2C_ADDRESS,PCA9622_I2C_ADDRESS,1,&generalsettings,1,10);
  System::Delay(1);
  //set mode2 register to zero
  i2c.WriteDataAtAddress(PCA9622_I2C_ADDRESS,PCA9622_I2C_ADDRESS+1,1,&generalsettings,1,10);
  System::Delay(1);
  //Set LEDs to enable PWM output
  for(int i = 0; i<4; i++)
  {
    i2c.WriteDataAtAddress(PCA9622_I2C_ADDRESS,0x14+i,1,&pwmsettings,1,10);
    System::Delay(1);
  }
}

void shiftvoices()
{
  uint8_t temp;
  temp = voicehist[3];
  voicehist[3] = voicehist[2];
  voicehist[2] = voicehist[1];
  voicehist[1] = voicehist[0];
  voicehist[0] = temp;
}

void voiceOFF(uint8_t note)
{
  for(int i = 0; i<4; i++)
  {
    if((voicetrig[i] == 1) && (note == voicenote[i]))
    {
      voicetrig[i] = 0;
    }
  }
  if (gate_out && voicetrig[0] == 0 && voicetrig[1] == 0 && voicetrig[2] == 0 && voicetrig[3] == 0 )
  {
    gate_out = 0;
    filtenv_trig = 0;
  }

}


void voiceON(uint8_t note)
{
  float freq_note = mtof(note - 1) * pbend * octaveindex[octave];
  
  if (!gate_out)
  {
    gate_out = 1;
    filtenv_trig = 1;
  }
  for(int i = 0; i<4; i++)
  {
    if(voicehist[0] == i+1 && !voicetrig[i])
    {
      voicenote[i] = note;
      voicetrig[i] = 1;
      shiftvoices();
      voicefreq[i] = freq_note;
      if(envelope[i].env.IsRunning())
      {
        envelope[i].env.Retrigger(0);
      }
      return;
     }
  }
 
}

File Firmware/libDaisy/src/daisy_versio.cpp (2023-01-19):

#include "daisy_versio.h"

using namespace daisy;

#define PIN_TRIG_IN 24
#define PIN_SW 30
#define PIN_TOGGLE3_0A 6
#define PIN_TOGGLE3_0B 5
#define PIN_TOGGLE3_1A 1
#define PIN_TOGGLE3_1B 0

#define PIN_LED0_R 10
#define PIN_LED0_G 3
#define PIN_LED0_B 4
#define PIN_LED1_R 12
#define PIN_LED1_G 13
#define PIN_LED1_B 11
#define PIN_LED2_R 25
#define PIN_LED2_G 26
#define PIN_LED2_B 14
#define PIN_LED3_R 29
#define PIN_LED3_G 27
#define PIN_LED3_B 15

#define PIN_ADC_CV0 21
#define PIN_ADC_CV1 22
#define PIN_ADC_CV2 28
#define PIN_ADC_CV3 23
#define PIN_ADC_CV4 16
#define PIN_ADC_CV5 17
#define PIN_ADC_CV6 19


void DaisyVersio::Init(bool boost)
{
    // seed init
    seed.Configure();
    seed.Init(boost);
    seed.SetAudioBlockSize(48);
    float blockrate_ = seed.AudioSampleRate() / (float)seed.AudioBlockSize();

    // pin numbers
    uint8_t toggle_pina[] = {PIN_TOGGLE3_0A, PIN_TOGGLE3_1A};
    uint8_t toggle_pinb[] = {PIN_TOGGLE3_0B, PIN_TOGGLE3_1B};
    uint8_t ledr_pin[]    = {PIN_LED0_R, PIN_LED1_R, PIN_LED2_R, PIN_LED3_R};
    uint8_t ledg_pin[]    = {PIN_LED0_G, PIN_LED1_G, PIN_LED2_G, PIN_LED3_G};
    uint8_t ledb_pin[]    = {PIN_LED0_B, PIN_LED1_B, PIN_LED2_B, PIN_LED3_B};
    uint8_t adc_pin[]     = {PIN_ADC_CV0,
                         PIN_ADC_CV1,
                         PIN_ADC_CV2,
                         PIN_ADC_CV3,
                         PIN_ADC_CV4,
                         PIN_ADC_CV5,
                         PIN_ADC_CV6};

    // gate in and momentary switch
    tap.Init(seed.GetPin(PIN_SW));
    dsy_gpio_pin gate_gpio = seed.GetPin(PIN_TRIG_IN);
    gate.Init(&gate_gpio);


    // 3-position switches
    for(size_t i = 0; i < SW_LAST; i++)
    {
        sw[i].Init(seed.GetPin(toggle_pina[i]), seed.GetPin(toggle_pinb[i]));
    }

    // ADC
    AdcChannelConfig adc_cfg[KNOB_LAST];
    for(size_t i = 0; i < KNOB_LAST; i++)
    {
        adc_cfg[i].InitSingle(seed.GetPin(adc_pin[i]));
    }
    seed.adc.Init(adc_cfg, 7);

    for(size_t i = 0; i < KNOB_LAST; i++)
    {
        knobs[i].Init(seed.adc.GetPtr(i), blockrate_, true);
    }

    // RGB LEDs
    for(size_t i = 0; i < LED_LAST; i++)
    {
        dsy_gpio_pin r = seed.GetPin(ledr_pin[i]);
        dsy_gpio_pin g = seed.GetPin(ledg_pin[i]);
        dsy_gpio_pin b = seed.GetPin(ledb_pin[i]);
        leds[i].Init(r, g, b, true);
    }
}

void DaisyVersio::SetHidUpdateRates()
{
    for(size_t i = 0; i < KNOB_LAST; i++)
    {
        knobs[i].SetSampleRate(AudioCallbackRate());
    }
}


void DaisyVersio::StartAudio(AudioHandle::InterleavingAudioCallback cb)
{
    seed.StartAudio(cb);
}

void DaisyVersio::StartAudio(AudioHandle::AudioCallback cb)
{
    seed.StartAudio(cb);
}

void DaisyVersio::ChangeAudioCallback(AudioHandle::InterleavingAudioCallback cb)
{
    seed.ChangeAudioCallback(cb);
}

void DaisyVersio::ChangeAudioCallback(AudioHandle::AudioCallback cb)
{
    seed.ChangeAudioCallback(cb);
}

void DaisyVersio::StopAudio()
{
    seed.StopAudio();
}

void DaisyVersio::SetAudioBlockSize(size_t size)
{
    seed.SetAudioBlockSize(size);
    SetHidUpdateRates();
}

size_t DaisyVersio::AudioBlockSize()
{
    return seed.AudioBlockSize();
}

void DaisyVersio::SetAudioSampleRate(SaiHandle::Config::SampleRate samplerate)
{
    seed.SetAudioSampleRate(samplerate);
    SetHidUpdateRates();
}

float DaisyVersio::AudioSampleRate()
{
    return seed.AudioSampleRate();
}

float DaisyVersio::AudioCallbackRate()
{
    return seed.AudioCallbackRate();
}

void DaisyVersio::StartAdc()
{
    seed.adc.Start();
}

void DaisyVersio::StopAdc()
{
    seed.adc.Stop();
}

void DaisyVersio::ProcessAnalogControls()
{
    for(size_t i = 0; i < KNOB_LAST; i++)
    {
        knobs[i].Process();
    }
}

bool DaisyVersio::SwitchPressed()
{
    return tap.Pressed();
}

bool DaisyVersio::Gate()
{
    return !gate.State();
}

void DaisyVersio::SetLed(size_t idx, float red, float green, float blue)
{
    leds[idx].Set(red, green, blue);
}

void DaisyVersio::DelayMs(size_t del)
{
    seed.DelayMs(del);
}

void DaisyVersio::UpdateLeds()
{
    for(size_t i = 0; i < LED_LAST; i++)
    {
        leds[i].Update();
    }
}

float DaisyVersio::GetKnobValue(int idx)
{
    return knobs[idx].Value();
}

void DaisyVersio::UpdateExample()
{
    tap.Debounce();
    for(size_t i = 0; i < LED_LAST - 1; i++)
        SetLed(i, 0, 0, 0);

    SetLed(sw[0].Read(), knobs[0].Value(), knobs[1].Value(), knobs[2].Value());
    SetLed(sw[1].Read(), knobs[3].Value(), knobs[4].Value(), knobs[5].Value());

    SetLed(3, Gate(), SwitchPressed(), knobs[6].Value());
}

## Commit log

2023-01-19 upload firmware
    [DSP.kicad_sch, Daisy_Seed_Rev4_Pinout.csv, erase_f0xx.cfg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]
2023-02-11 upload everything
    [BOM-fjol-desktop.csv, BOM-frontpanel(1).csv, DSP.kicad_sch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]
